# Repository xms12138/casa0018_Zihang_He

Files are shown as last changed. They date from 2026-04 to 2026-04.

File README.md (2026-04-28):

# 💡 EchoLume: An Offline Voice-Controlled Adaptive Smart Lamp on the Edge






## 📖 Overview

Smart lamps that respond to voice are everywhere, but the dominant pattern sends audio off-device for cloud inference—trading user privacy and network dependency for accuracy. **EchoLume asks whether that trade is necessary for a simple four-command desk lamp.**

EchoLume is a fully offline, privacy-preserving smart lamp running an INT8-quantised keyword-spotting model entirely on an **Arduino Nano 33 BLE Sense (Cortex-M4F, 64 MHz)**. It processes audio locally, utilizes a lightweight 1D CNN to recognize commands (`turn_on`, `turn_off`, `reading`, `sleep`), and uses a Finite State Machine (FSM) to drive an addressable LED strip.

> **Note:** This repository is forked from the UCL CASA0018 module. All of my final project code, models, and comprehensive documentation are located in the [`Assessment`](./Assessment) directory.

---

## 🛠️ Repository Navigation & Reproduction

To replicate this project or view the source files, navigate to the [`Assessment/Projects/Final_Project`](./Assessment/Projects/Final_Project) directory.

### Directory Structure

* 📄 **[`Report/`](./Assessment/Report)**: The final academic report (`report.md`) detailing problem context, datasets, and critical reflections.
* 💻 **[`arduino/`](./Assessment/Projects/Final_Project/arduino)**: The deployment firmware (`.ino`) containing the FSM and LED control logic.
* 🧠 **[`edge_impulse/`](./Assessment/Projects/Final_Project/edge_impulse)**: Exported INT8 C++ libraries from the training pipeline.
* 📊 **[`experiments/`](./Assessment/Projects/Final_Project/experiments)**: Detailed experiment logs and JSON configs.
* 🖨️ **[`3D_Printer/`](./Assessment/Projects/Final_Project/3D_Printer)**: Enclosure CAD/STL files.

### Hardware Setup

1. **Board:** Arduino Nano 33 BLE Sense
2. **Actuator:** WS2812B Addressable LED strip (Data pin wired to `D2`, powered via the 3.3V rail).
3. **Dependencies:** Install the Edge Impulse `.zip` library (found in the `edge_impulse/` folder) into your Arduino IDE.

------

## ⚙️ System Architecture

The signal path is a highly optimized five-stage pipeline designed to fit within the stringent 100 ms real-time budget and 256 KB RAM of the Cortex-M4F.

<p align="center">
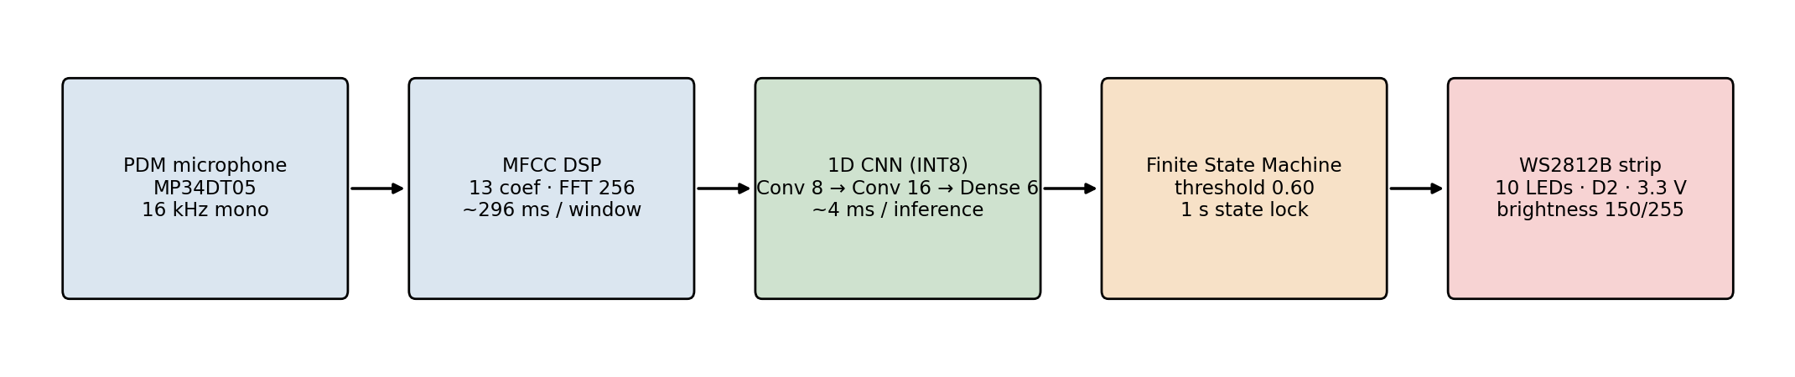
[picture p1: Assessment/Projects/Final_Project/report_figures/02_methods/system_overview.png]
System Signal Path Overview
  
</p>

1. **Audio Capture:** On-board MP34DT05 PDM microphone (16 kHz mono).
2. **DSP (MFCC):** Extracts 13 cepstral coefficients per 1 s sliding window. 
   * *Engineering Decision:* EI Autotune suggested an FFT length of 512, which cost 416 ms (unusable for real-time). **I manually reduced the FFT length to 256, dropping DSP time to 296 ms (−29%)** with no visible loss of feature separability.
3. **1D CNN (INT8):** A sub-50 KB convolutional network processes the features.
4. **Finite State Machine:** A 1-second state-lock acts as a low-pass filter, preventing erratic flickering. Predictions below a 0.60 confidence threshold are safely ignored.

<p align="center">
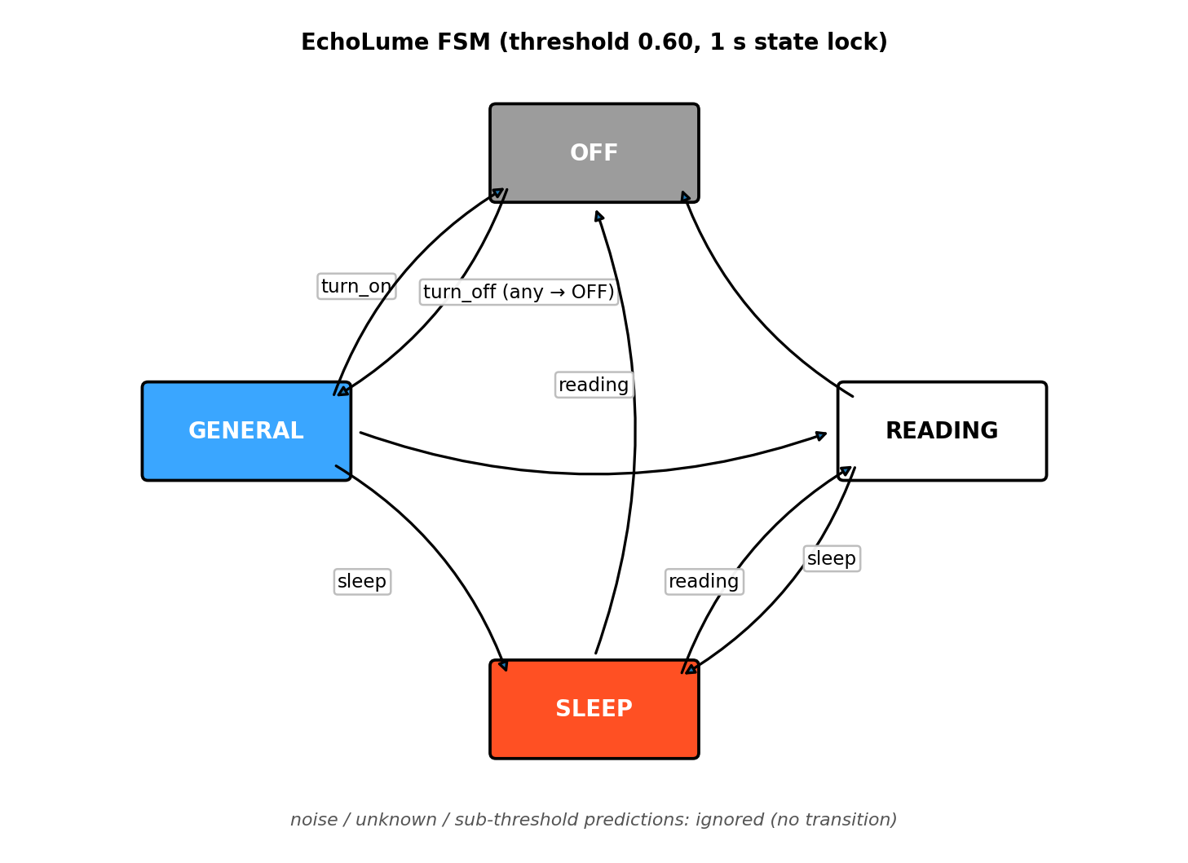
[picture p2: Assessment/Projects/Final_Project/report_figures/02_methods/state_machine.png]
FSM Diagram
  
</p>

---

## 🔬 Experiments & Model Selection

The goal was not merely to chase headline accuracy, but to find a model that fails *safely*. Three architectures were rigorously tested.

| Metric | baseline (Conv 8/16) | exp_wider (Conv 16/32) | exp_dense (No Conv) |
| --- | --- | --- | --- |
| **Test Acc (INT8 @ 0.6)** | **81.95%** | 82.93% | 61.95% ❌ |
| **`turn_on` -> `turn_off` Error** | **10.0%** | 33.3% ❌ | 23.3% ❌ |
| **Peak RAM (KB)** | 12.5 | 14.0 | 1.8 |
| **Flash (KB)** | 46.4 | 49.4 | 34.1 |
| **Inference Time (ms)** | 4 | 7 | 1 |
| **Verdict** | **Deployed (Safest Failure Mode)** | Rejected (Wrong-action failure) | Rejected (Noise blind) |

### 🔍 Key Findings
* **Capacity is not the bottleneck (Wider != Better):** Doubling the convolutional channels (`exp_wider`) increased overall accuracy by +1 pp, but caused a **3.3x rise in confidently-wrong triggers** (confusing `turn_on` for `turn_off`). The baseline model politely fails into "uncertainty" (no action), making it strictly better for an FSM application.
* **Convolutions are load-bearing:** Replacing the CNN with a Dense head (`exp_dense`) collapsed accuracy by 20 pp and made the model essentially blind to background noise (40% accuracy on `noise`). 

<p align="center">
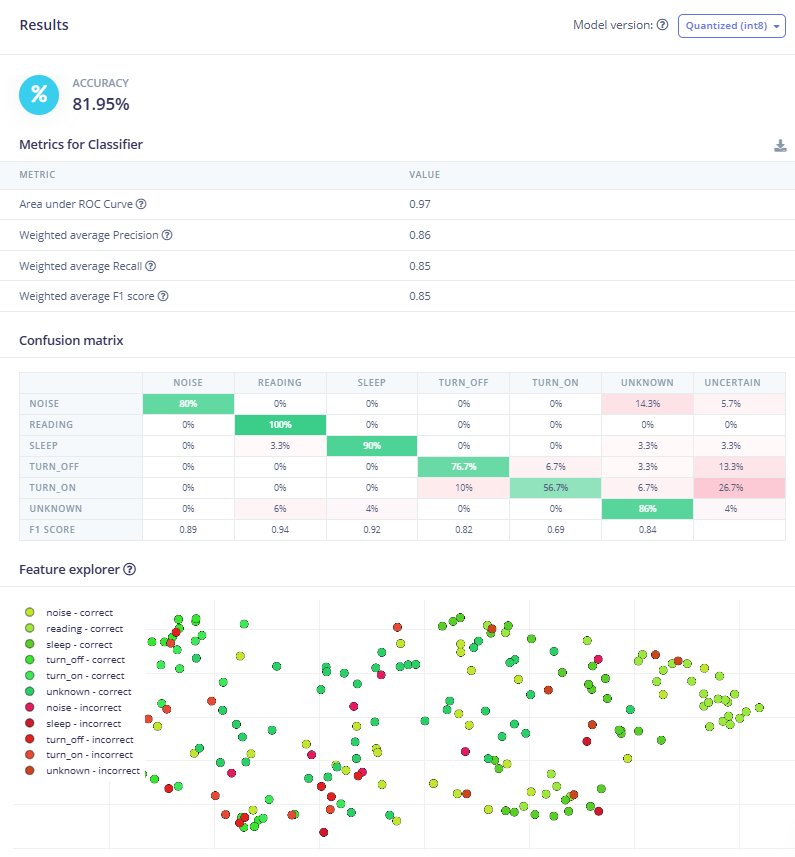
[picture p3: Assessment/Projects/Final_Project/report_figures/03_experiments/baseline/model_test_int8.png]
Baseline Confusion Matrix
  
  <br>
  <em>Figure: Baseline INT8 Test-Set Confusion Matrix. Note the safe concentration of errors in the UNCERTAIN column.</em>
</p>

---

## 📊 Real-World Performance (Live Testing)

The shipped baseline firmware was deployed on-device and tested via **100 live spoken trials** in a real-world desk environment (varying distances 0.05m–0.5m, with occasional background music).

* **Aggregate Correct Transitions:** **88.0%**
* Live recall actually *exceeded* the static Edge Impulse test set because the FSM's 1-second state lock successfully collapses uncertain acoustic frames into benign "no actions".

<p align="center">
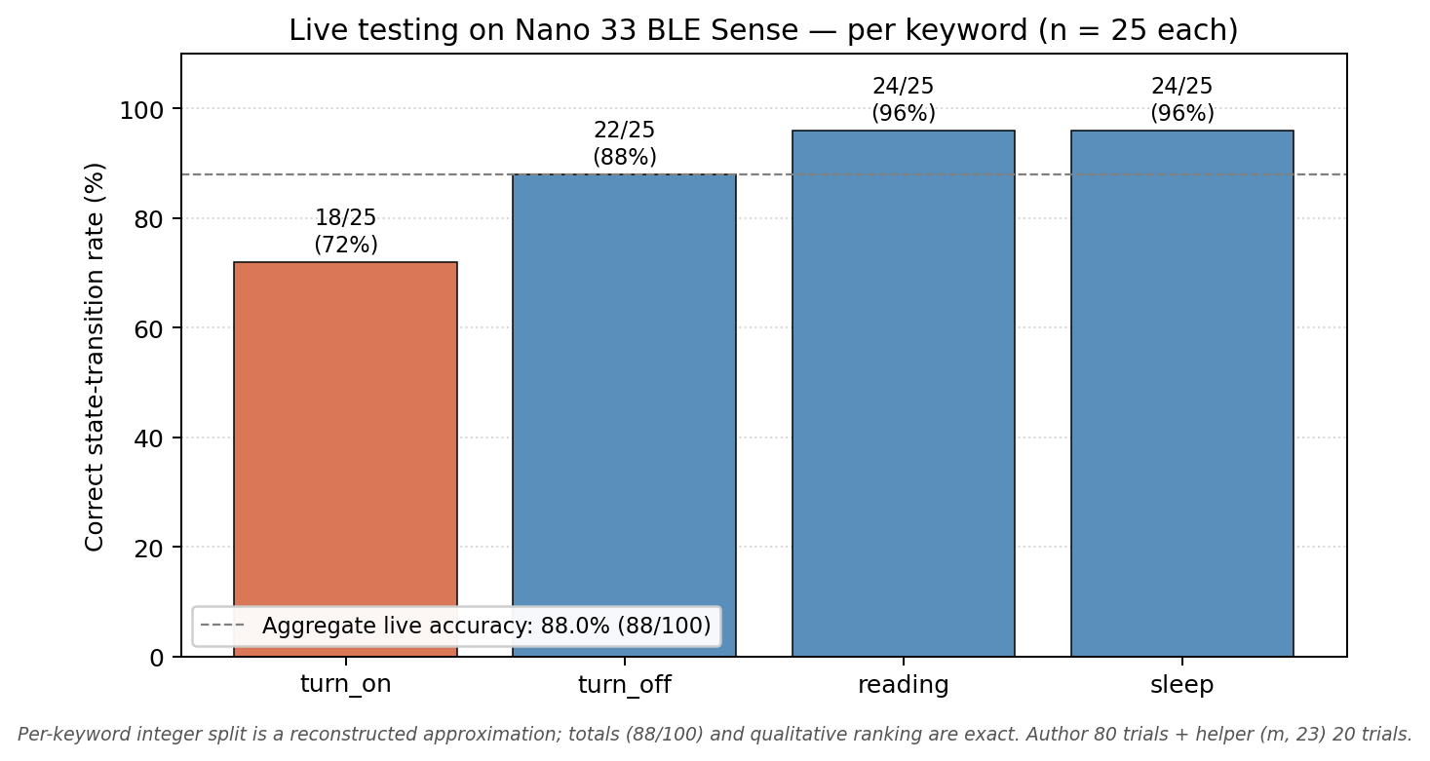
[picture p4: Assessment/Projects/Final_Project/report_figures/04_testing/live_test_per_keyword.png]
Live Testing per Keyword
  
</p>
---
*Authored by **Zihang He** for CASA0018: Deep Learning for Sensor Networks.*

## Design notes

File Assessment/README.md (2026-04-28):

# CASA0018 DL4SN Assessment Submission

**Author:** Zihang He  
**Module:** CASA0018 Deep Learning for Sensor Networks (DL4SN)

Welcome to my final assessment repository. This folder contains all the documentation, source code, and assets for my coursework, demonstrating the process of taking machine learning out of the cloud and deploying it locally on an edge device.

The centerpiece of this submission is my final project: **EchoLume**.

> **Note:** For more specific details about the project, please visit the [Main Repository](https://github.com/xms12138/casa0018_Zihang_He/tree/main).

---

## 📂 Repository Structure

In accordance with the module guidelines, this assessment repository is organized into two main parts:

### 1. [Report](./Report)
This folder contains the comprehensive documentation of my final project.
* `report.md`: The final project report (approx. 1600 words) detailing the problem context, custom data collection, iterative model testing, and critical reflection.

### 2. [Projects/Final_Project](./Projects/Final_Project)
This folder acts as the technical hub for the EchoLume project. It contains all the code and assets required to replicate the physical build and the machine learning pipeline:
* **`arduino/`**: The deployment firmware in C++ for the Arduino Nano 33 BLE Sense, integrating the Edge Impulse model, the PDM microphone, and the finite state machine (FSM) for the WS2812B LEDs.
* **`edge_impulse/`**: Exported models and configuration files from the Edge Impulse platform.
* **`experiments/`**: Documentation and data analyzing the different model architectures tested (e.g., Conv 8/16 vs. Conv 16/32 vs. Dense).
* **`3D_Printer/`**: CAD files and assets used for the physical enclosure of the smart lamp.
* **`scripts/`**: Python utility scripts used during the data processing and analysis phases.
* **`report_figures/`**: All visual assets, graphs, and hardware photos used in the main report.

---

## 💡 About the Final Project: EchoLume

**EchoLume** is an offline, privacy-preserving smart lamp running an INT8-quantised keyword-spotting model entirely on an Arduino Nano 33 BLE Sense (Cortex-M4F). 

It proves that everyday smart home interactions do not strictly require cloud connectivity. The system captures speech via the on-board PDM microphone, processes it through an MFCC front-end and a lightweight 1D CNN, and drives an addressable LED strip via a finite state machine. It responds reliably to four distinct commands (`turn_on`, `turn_off`, `reading`, `sleep`) while gracefully ignoring background noise and unknown utterances.

---

## 🚀 How to Use / Getting Started

To build and run EchoLume locally, follow these hardware and software setup instructions.

### 🛠️ Hardware Requirements
* 1x **Arduino Nano 33 BLE Sense**
* 1x **WS2812B Addressable LED Strip** (10 LEDs are used in the default configuration)
* Jumper wires and a breadboard
* (Optional) 3D printed enclosure (files available in the `3D_Printer/` folder)

### 🔌 Wiring
Connect the WS2812B LED strip to the Arduino Nano 33 BLE Sense as follows:
* **LED VCC** -> Arduino **3.3V** (Make sure brightness is capped in code to avoid drawing too much current)
* **LED GND** -> Arduino **GND**
* **LED Data (DIN)** -> Arduino **D2**

### 💻 Software Setup & Installation
1. **Install Arduino IDE:** Download and install the [Arduino IDE](https://www.arduino.cc/en/software).
2. **Install Board Core:** Open the Arduino IDE, go to `Tools -> Board -> Boards Manager...`, and install the **Arduino Mbed OS Nano Boards** package.
3. **Install the Edge Impulse Library:**
   * Locate the custom Edge Impulse exported `.zip` library in this repository under `Projects/Final_Project/edge_impulse/`.
   * In the Arduino IDE, navigate to `Sketch -> Include Library -> Add .ZIP Library...` and select the `.zip` file.
4. **Flash the Firmware:**
   * Open the EchoLume firmware sketch located at `Projects/Final_Project/arduino/echolume/echolume.ino`.
   * Connect your Arduino Nano 33 BLE Sense to your computer. Select the correct Board and Port in the `Tools` menu.
   * Click **Upload**.

### 🎙️ Usage
Once the firmware is uploaded and the board is powered on:
1. The on-board PDM microphone will continuously listen to the environment.
2. Speak one of the four action keywords: **"Turn on"**, **"Turn off"**, **"Reading"**, or **"Sleep"**.
3. The LED strip will adapt to the corresponding lighting scene.
   * *Note: The Finite State Machine (FSM) incorporates a 1-second state lock to prevent erratic flickering, and it ignores audio classifications that fall below the 0.60 confidence threshold.*

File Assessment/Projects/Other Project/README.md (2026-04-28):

### [CASA0018 Lab 4: 部署余弦波模型到 Arduino](Assessment/Projects/Other%20Project/Lab4%20cos/)

- **训练笔记本**: [查看 sin to cos.ipynb](Assessment/Projects/Other%20Project/Lab4%20cos/sin%20to%20cos.ipynb)
- **Arduino 源代码**: [查看 hello_casa_custom 文件夹](Assessment/Projects/Other%20Project/Lab4%20cos/hello_casa_custom/)
- **模型文件**: [查看导出的 model.cpp 和 model.h](Assessment/Projects/Other%20Project/Lab4%20cos/models/)

#### 运行效果演示：
Arduino 2秒循环呼吸灯演示

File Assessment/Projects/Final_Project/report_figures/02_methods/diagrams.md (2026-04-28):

# Self-drawn diagrams (mermaid sources)

These three diagrams render natively on GitHub and can be embedded into the
report by either pasting the mermaid source, or by exporting each block to PNG
via the Mermaid Live Editor (https://mermaid.live) into this same directory.

---

## 1. System overview

```mermaid
flowchart LR
    A[Onboard PDM mic<br/>MP34DT05<br/>16 kHz mono] --> B[MFCC DSP<br/>13 coef · FFT 256<br/>~296 ms / window]
    B --> C[1D CNN INT8<br/>Conv 8 → Conv 16 → Dense 6<br/>~4 ms / inference]
    C --> D{best_value<br/>≥ 0.60 ?}
    D -- no --> A
    D -- yes --> E[Finite State Machine<br/>OFF · GENERAL · READING · SLEEP<br/>1 s state lock]
    E --> F[WS2812B strip<br/>10 LEDs · D2 · 3.3 V<br/>brightness 150/255]
```

---

## 2. State machine

```mermaid
stateDiagram-v2
    direction LR
    [*] --> OFF
    OFF --> GENERAL: turn_on
    GENERAL --> READING: reading
    GENERAL --> SLEEP: sleep
    READING --> SLEEP: sleep
    SLEEP --> READING: reading
    GENERAL --> OFF: turn_off
    READING --> OFF: turn_off
    SLEEP --> OFF: turn_off

    note right of OFF
        Colour: all off
    end note
    note right of GENERAL
        Colour: ice blue (0,255,200)
    end note
    note right of READING
        Colour: pure white (255,255,255)
    end note
    note right of SLEEP
        Colour: warm orange-red (255,50,0)
    end note
```

`noise` and `unknown` predictions are silently ignored (no transition).
Predictions with `best_value < 0.60` are treated as `uncertain` and ignored.
A 1 s state lock after each accepted transition prevents a single utterance
being re-classified across multiple frames.

---

## 3. Model architecture (baseline)

```mermaid
flowchart TB
    A["Input<br/>637 features<br/>flat vector from MFCC"] --> B["Reshape<br/>13 columns<br/>(time × cepstral)"]
    B --> C["Conv1D<br/>8 filters · kernel 3 · ReLU"]
    C --> D["Dropout 0.25"]
    D --> E["Conv1D<br/>16 filters · kernel 3 · ReLU"]
    E --> F["Dropout 0.25"]
    F --> G["Flatten"]
    G --> H["Dense 6 · softmax<br/>{turn_on, turn_off, reading, sleep, noise, unknown}"]
```

INT8 quantization applied post-training. On-device estimate (Cortex-M4F):
~4 ms inference, ~12.5 KB peak RAM, ~46.4 KB flash.

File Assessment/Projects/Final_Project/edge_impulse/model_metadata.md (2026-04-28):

# Model Metadata

- **Edge Impulse project URL (public)**: https://studio.edgeimpulse.com/public/973891/latest
- **Project ID**: 973891
- **Project name (EI Studio)**: `xms.12138-project-1`
- **Exported library**: `exported_library/ei-xms.12138-project-1-arduino-1.0.1-impulse-#1.zip`
- **Last sync**: 2026-04-28

## Impulse summary

| Block | Setting | Value |
|---|---|---|
| DSP | type | MFCC |
| DSP | coefficients | 13 |
| DSP | frame length / stride | 0.025 s / 0.02 s |
| DSP | FFT length | 256 (manual; autotune default 512 — see exp_log) |
| DSP | filter number | 32 |
| DSP | low frequency | 80 Hz |
| DSP | output features | 637 (reshape 13 cols) |
| Model | architecture | EI default 1D CNN (Conv 8 → Conv 16 → Flatten → Dense 6) |
| Model | dropout | 0.25 (×2) |
| Training | epochs / lr / batch | 200 / 0.005 / 32 |
| Training | augmentation | Add noise Low + Mask time Low + Mask freq Low + Warp time on |
| Training | learned optimizer | disabled |
| Quantization | mode | INT8 (also Float32 evaluated for comparison) |

## Performance snapshot — baseline (INT8 unless noted)

| Metric | Value |
|---|---|
| Validation accuracy (INT8) | 94.5% |
| Validation accuracy (Float32) | 95.1% |
| Test accuracy @ threshold 0.6 (INT8) | 81.95% |
| Test accuracy @ threshold 0.6 (Float32) | 82.44% |
| Quantization Δ (test) | −0.49 pp |
| Validation → Test gap | −12.55 pp |
| Worst-class F1 (INT8 test) | turn_on 0.69 |
| On-device inference (INT8 est.) | ~4 ms |
| On-device DSP | 296 ms |
| Peak RAM (INT8 est.) | ~12.5 KB |
| Flash (INT8 est.) | ~46.4 KB |

## Live testing (deployed Nano 33 BLE Sense, threshold 0.6)

| Metric | Value |
|---|---|
| Total trials | 100 |
| Correct state transitions | 88 |
| Aggregate live accuracy | 88.0% |

See `experiments/exp_log.md` entry 2026-04-28 for protocol, per-speaker split, and per-keyword breakdown.

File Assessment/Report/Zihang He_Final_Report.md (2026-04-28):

# EchoLume: An Offline Voice-Controlled Adaptive Smart Lamp on the Edge

**Zihang He** &nbsp;·&nbsp; [GitHub](https://github.com/xms12138/casa0018_Zihang_He/tree/main/Assessment) &nbsp;·&nbsp; [Edge Impulse public project](https://studio.edgeimpulse.com/public/973891/latest)

## Introduction

Smart lamps that respond to voice are now everywhere, but the dominant pattern — Alexa, Google Home and similar — sends audio off-device for cloud inference, trading user privacy and a working internet connection for accuracy. EchoLume asks whether that trade is necessary for a four-command desk lamp.

EchoLume is an offline, privacy-preserving smart lamp running an INT8-quantised keyword-spotting model entirely on an Arduino Nano 33 BLE Sense (Cortex-M4F, 64 MHz). Audio never leaves the board: the on-board PDM microphone captures speech, an MFCC front-end and a 1D CNN classify it, and a finite state machine drives a WS2812B addressable LED strip. Four control words — `turn_on`, `turn_off`, `reading`, `sleep` — switch the lamp between ambient, reading and rest scenes; two distractor classes (`noise`, `unknown`) absorb non-target sounds.

The implementation builds on Warden's _Speech Commands_ dataset (Warden, 2018) and the _Hello Edge_ line of micro-controller keyword spotting (Zhang et al., 2017), with Edge Impulse as the training-and-export harness. The contribution this report documents is not a novel architecture but a structured exploration of the design space — what stays in budget, what improves the failure mode, and what does not.

<p align="center">
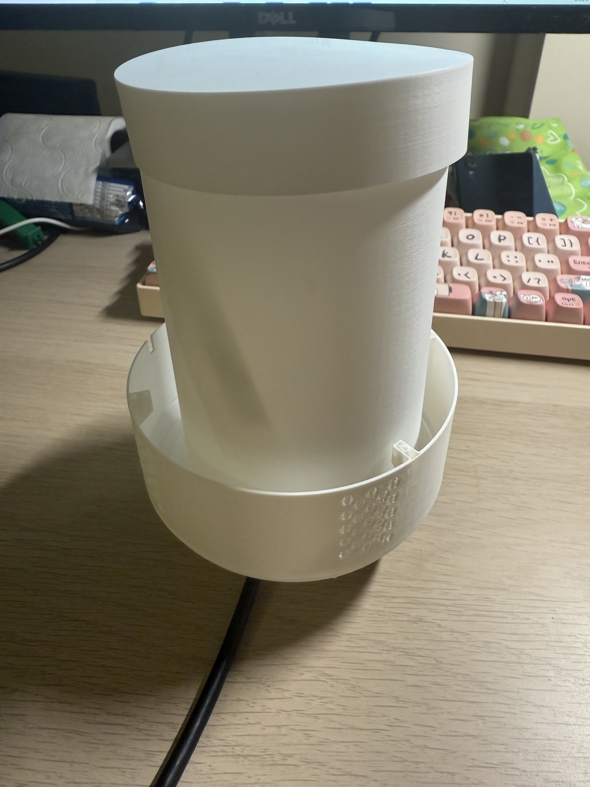
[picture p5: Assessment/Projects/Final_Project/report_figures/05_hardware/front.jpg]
  
</p>

_Figure 1. EchoLume on a desk._

## Research Question

Can a sub-50 KB INT8 keyword-spotting model deployed on a Cortex-M4F microcontroller deliver reliable, fully offline voice control of an addressable RGB lamp under realistic desk-use conditions?

## Application Overview

The signal path is a five-stage pipeline (Figure 2). The on-board MP34DT05 PDM microphone samples at 16 kHz mono. An MFCC block produces a 637-feature vector per 1 s sliding window — 13 cepstral coefficients across roughly 49 frames — which is reshaped to a 13-column matrix and fed to a 1D CNN exported as INT8 from Edge Impulse. The classifier outputs a softmax over six classes; predictions whose top-1 probability falls below 0.60 are treated as `uncertain` and ignored.

Above the classifier sits a finite state machine (Figure 3) that converts the keyword stream into a lamp scene. Four lamp states (OFF, GENERAL, READING, SLEEP) are linked by legal transitions: `turn_on` is honoured only from OFF, `turn_off` from any non-OFF state, and `reading` and `sleep` toggle scenes within the on-states. A 1 s state-lock prevents a single utterance being re-classified across consecutive frames. The LED strip (10 WS2812B pixels driven from the Nano's 3.3 V rail on D2) renders the active state as ice-blue, white or warm orange-red.

This separation matters: the FSM lets the system fail gracefully. If the classifier returns a low-confidence prediction, the FSM drops it; if it returns an illegal one (e.g. `sleep` while OFF), the FSM ignores it. Failures collapse into "no action" rather than "wrong action".

<p align="center">
  
</p>

_Figure 2. EchoLume signal-path overview._

<p align="center">
  
</p>

_Figure 3. Lamp state machine (threshold 0.60, 1 s state lock). `noise`, `unknown` and sub-threshold predictions are ignored._

## Data

The dataset comprises 1,025 one-second utterances across six classes (Figure 4). The four action classes (`turn_on`, `turn_off`, `reading`, `sleep`) are 150 self-recorded samples each, captured on the same Nano 33 BLE Sense microphone the system later runs inference on, removing one source of acoustic distribution shift between training and deployment.

Two distractor classes back the action vocabulary against a noisy environment. `noise` (175 samples) is drawn from the MS-SNSD noisy-speech dataset (Reddy et al., 2019) via Edge Impulse's public datasets. `unknown` (250 samples) is a balanced subset of Google Speech Commands V2 (Warden, 2018) with the four target words filtered out. The 80/20 train/test split is applied uniformly; Edge Impulse subdivides 20 % of training for validation during model fitting.

The action classes are balanced and the distractor classes deliberately oversampled, on the heuristic that a keyword spotter's ability to _not_ fire matters as much as its ability to fire. The single largest known limitation is that all 600 action samples come from one primary speaker — a generalisation risk addressed in _Results_.

<p align="center">
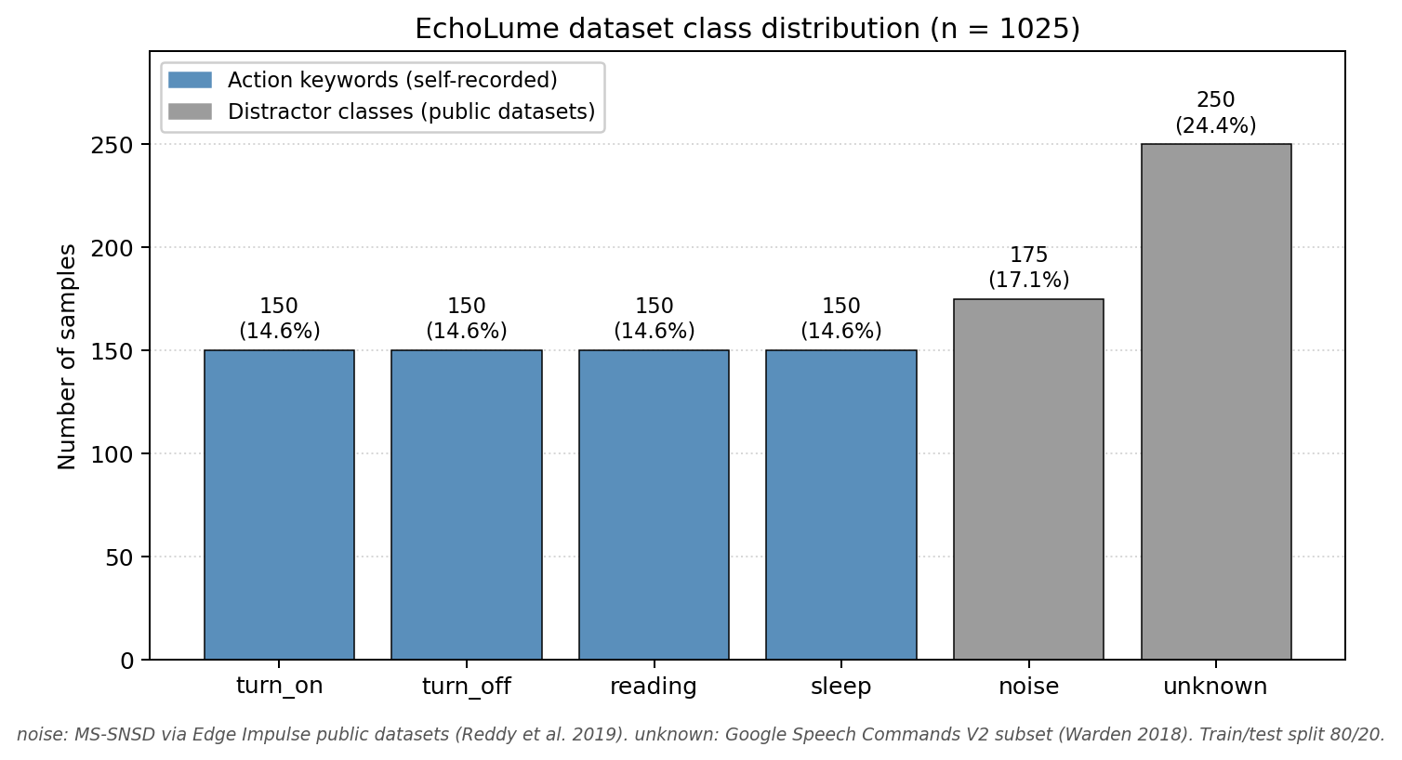
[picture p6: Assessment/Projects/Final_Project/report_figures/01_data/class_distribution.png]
  
</p>

_Figure 4. Dataset class distribution (n = 1,025)._

## Model

The baseline model is the Edge Impulse default 1D CNN (Figure 5): two stacked Conv1D blocks (8 and 16 filters, kernel 3, ReLU, each followed by 25 % dropout), a Flatten, and a six-way softmax. Reshaping the 637-feature input to 13 columns gives the convolutions the time × cepstral structure they need to learn local spectro-temporal patterns; the modest filter count keeps INT8 weights well under the Nano's 1 MB flash and 256 KB RAM.

The DSP block was the first non-trivial design decision. Edge Impulse's autotune recommended an FFT length of 512, which produced a per-window DSP cost of 416 ms on the Cortex-M4F — over four times the 100 ms real-time budget for a keyword loop. Manually reducing the FFT length to 256 cut DSP to 296 ms (−29 %) with no visible loss of separability in the feature explorer. Inference itself remains 4 ms; DSP is the dominant cost, and the choice is a deliberate trade between window-rate latency and frequency resolution.

Training used 200 epochs, learning rate 0.005, batch 32, with the Edge Impulse augmentation stack at "Low" intensity (additive noise, time and frequency masking, time warp). Quantisation is post-training INT8.

<p align="center">
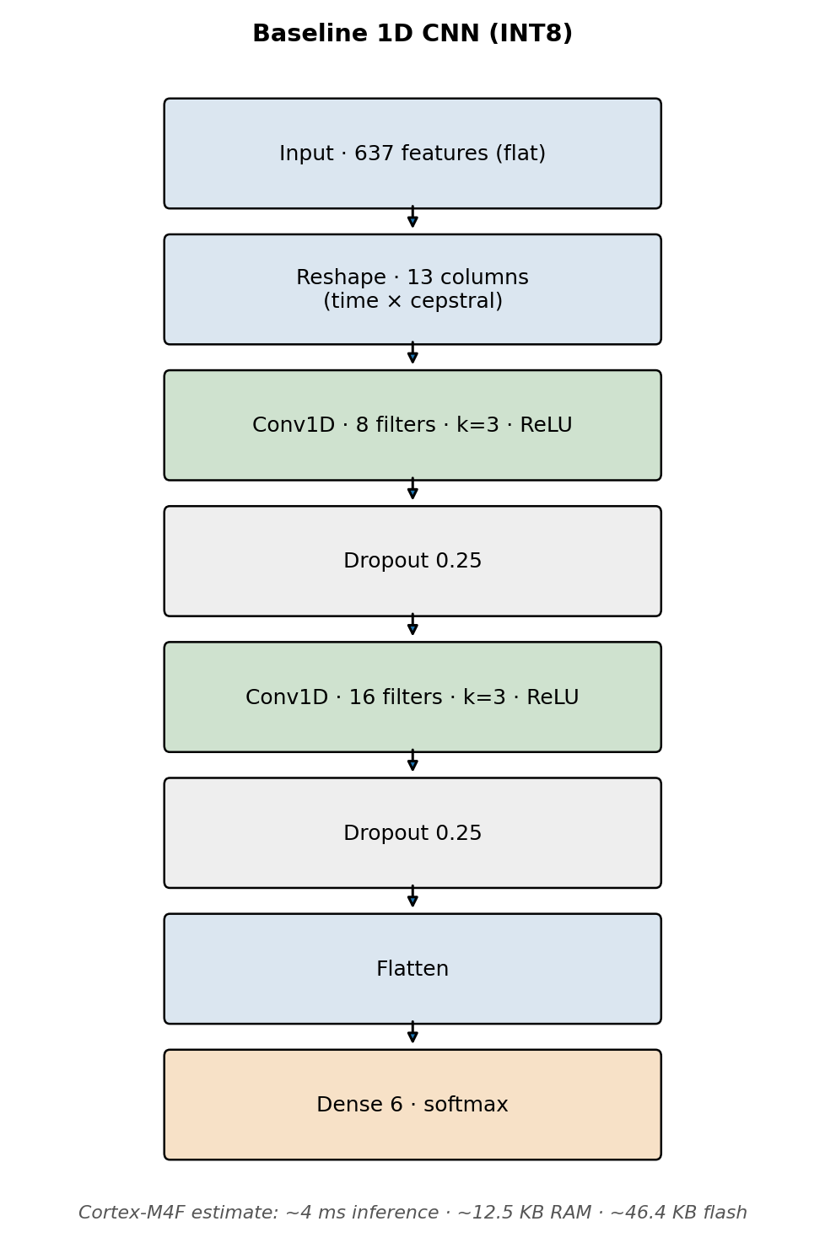
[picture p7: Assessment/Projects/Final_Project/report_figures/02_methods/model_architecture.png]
  
</p>

_Figure 5. Baseline 1D CNN architecture._

## Experiments

Three architectures were compared on the same DSP, augmentation and training schedule. The goal was not to chase headline accuracy, but to test which architectural choices are load-bearing for this data and which are decorative.

**Baseline (Conv 8/16).** Validation 94.5 % INT8 (95.1 % Float32); test 81.95 % INT8 at threshold 0.6 (82.44 % Float32). The val→test gap of −12.55 pp is far larger than the −0.49 pp INT8 quantisation cost — generalisation, not quantisation, is the bottleneck. Per-class F1 ranks `reading` 0.94, `sleep` 0.92, `noise` 0.89, `unknown` 0.84, `turn_off` 0.82, `turn_on` 0.69. The `turn_on`/`turn_off` pair is the structural weak spot: the two utterances share their first ~800 ms; only the trailing fricative differs. On-device profile: 4 ms inference, 12.5 KB RAM, 46.4 KB flash.

**exp_wider (Conv 16/32).** Doubling the convolutional channels was hypothesised to capture finer fricative-tail differences. Headline metrics improved (val 96.3 % INT8, test 82.93 %, `turn_on` F1 → 0.76), but the per-class breakdown reveals a worse failure mode: `turn_on → turn_off` confusion rose from 10 % to 33 % (×3.3). The wider model trades polite "uncertain → no response" failures for confident "wrong-action" failures — a regression for a state-machine application. Capacity is not the bottleneck; calibration is.

**exp_dense (no Conv).** Replacing both Conv1D blocks with a single Dense 32 head tested whether MFCC features alone make the convolutions redundant. They do not: test accuracy collapses to 61.95 % (−20 pp), `noise` to 40 %, `turn_on` to 43 %. The dense head memorises validation patterns (its `turn_on` validation recall is 90 %) but does not generalise. Convolutions do real work even at this scale, and the experiment locks Conv1D in as load-bearing for the rest of the design.

| Metric | baseline | exp_wider | exp_dense |
| --- | --- | --- | --- |
| Val acc (INT8) | 94.5 % | **96.3 %** | 75.0 % |
| Test acc @ 0.6 (INT8) | 81.95 %  | **82.93 %** | 61.95 % |
| `turn_on` F1 | 0.69 | 0.76 | 0.55 |
| `turn_on → turn_off`  | 10 % | **33 %** | 23 % |
| Inference (ms) | 4 | 7 | 1 |
| Peak RAM (KB) | 12.5 | 14.0 | 1.8 |
| Flash (KB) | 46.4 | 49.4 | 34.1 |
| Verdict | shipped  | unsafe failure mode | confirms Conv is load-bearing |

_Table 1. Cross-experiment summary (INT8 unless noted)._

<p align="center">
  
</p>

_Figure 6. Baseline INT8 test-set confusion matrix (threshold 0.6)._

## Results and Observations

The shipped firmware uses the baseline INT8 model. A live-testing session of 100 trials (4 keywords × 25 trials, threshold 0.6, 1 s state lock) was conducted as a real-world check. Eighty trials were performed by the author and twenty by an additional speaker (m, 23, no prior exposure); mouth-to-mic distance varied 0.05–0.5 m, with half the trials run with light background music playing. A trial counted as correct only if the LED strip transitioned to the intended state.

The aggregate result was **88/100 = 88.0 %** correct transitions — author 71/80, helper 17/20. The per-keyword breakdown shown in Figure 7 (24/25 `reading`, 24/25 `sleep`, 22/25 `turn_off`, 18/25 `turn_on`) is approximate: per-trial outcomes were not logged at the time, so the integer split across keywords is reconstructed from in-session observations and is consistent with the baseline EI test-set ranking. Aggregates and qualitative ranking are exact.

Two findings stood out. First, live recall exceeded EI test-set recall on every keyword (Figure 8). The likely explanations are speaker overlap with training data, and the more lenient FSM-level criterion: the state-lock collapses many uncertain frames into a benign no-action rather than an explicit miss. Second, the dominant failure mode was no-response on `turn_on`, never wrong-state on `turn_on` — exactly the pattern predicted by the baseline confusion matrix. A separate failure mode appeared during the helper session: 1–2 false triggers caused by a bystander speaking nearby. These were not counted in the 12 listed failures because they were not logged at the time, but they are worth flagging as a real-world weakness.

<p align="center">
  
</p>

_Figure 7. Live-testing results per keyword (n = 25 each)._

<p align="center">
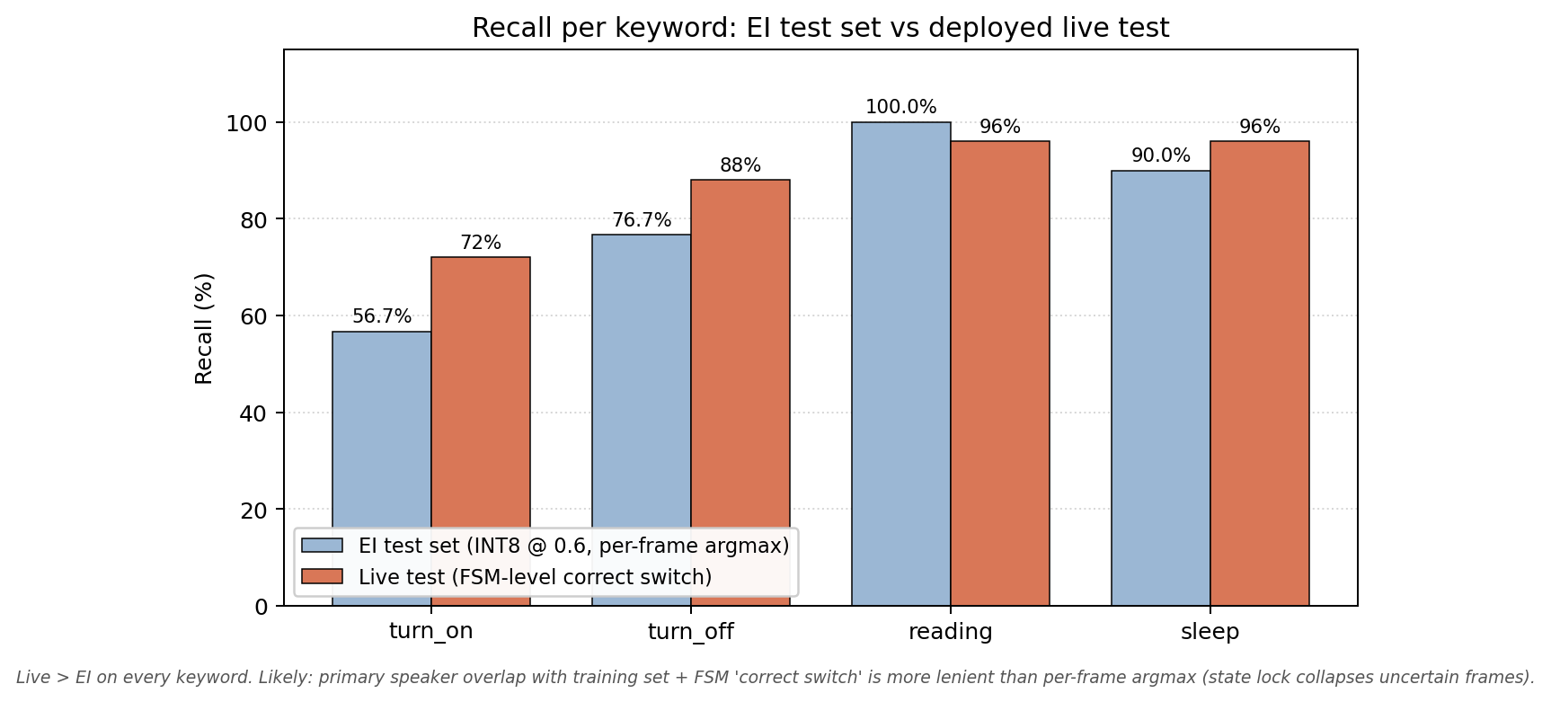
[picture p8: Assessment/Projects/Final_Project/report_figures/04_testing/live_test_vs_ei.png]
  
</p>

_Figure 8. Live test versus Edge Impulse test-set recall, per keyword._

**Limitations.** Three structural weaknesses are visible in the data above. (1) `turn_on` and `turn_off` share their leading 800 ms, leaving the model dependent on the trailing fricative — the worst class in every experiment. (2) The −12.55 pp val→test gap reflects a real distribution shift, almost certainly tied to (3) the dataset being recorded by a single primary speaker. Two further issues warrant brief mention: the 296 ms DSP cost still exceeds the 100 ms real-time budget but does not break functionality, since inference itself is only 4 ms; and the confidence threshold trades coverage for safety — 0.5 raises recall but lifts wrong-state errors, while 0.6 is the conservative pick. The bystander false-trigger mode points to a missing capability: without a wake-word gate or voice-activity threshold, sub-threshold utterances from the environment can still nudge state.

**What would I do next.** A multi-speaker re-recording of the action classes would directly attack the val→test gap. A wake-word stage (e.g. "EchoLume, …") would suppress bystander triggers. A small depthwise-separable variant of the Conv1D backbone is a candidate that keeps the Cortex-M4F budget within reach while improving calibration on the `turn_on`/`turn_off` boundary.

## Bibliography

1. Reddy, C. K. A., Beyrami, E., Pool, J., Cutler, R., Srinivasan, S., & Gehrke, J. (2019). _A Scalable Noisy Speech Dataset and Online Subjective Test Framework._ Interspeech 2019. https://arxiv.org/abs/1909.08050
2. Warden, P. (2018). _Speech Commands: A Dataset for Limited-Vocabulary Speech Recognition._ arXiv:1804.03209. https://arxiv.org/abs/1804.03209
3. Zhang, Y., Suda, N., Lai, L., & Chandra, V. (2017). _Hello Edge: Keyword Spotting on Microcontrollers._ arXiv:1711.07128. https://arxiv.org/abs/1711.07128

---

## Declaration of Authorship

I, Zihang He, confirm that the work presented in this assessment is my own. Where information has been derived from other sources, I confirm that this has been indicated in the work.

_Zihang He_

2026-04-28

Word count: 1648 (body text only — title, captions, tables, bibliography and declaration excluded).

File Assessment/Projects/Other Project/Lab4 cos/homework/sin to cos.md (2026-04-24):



# Train a Simple TensorFlow Lite for Microcontrollers model

This notebook demonstrates the process of training a 2.5 kB model using TensorFlow and converting it for use with TensorFlow Lite for Microcontrollers.

Deep learning networks learn to model patterns in underlying data. Here, we're going to train a network to model data generated by a [sine](https://en.wikipedia.org/wiki/Sine) function. This will result in a model that can take a value, `x`, and predict its sine, `y`.

The model created in this notebook is used in the [hello_world](https://github.com/tensorflow/tensorflow/tree/master/tensorflow/lite/micro/examples/hello_world) example for [TensorFlow Lite for MicroControllers](https://www.tensorflow.org/lite/microcontrollers/overview).

<table class="tfo-notebook-buttons" align="left">
  <td>
    <a target="_blank" href="https://colab.research.google.com/github/tensorflow/tensorflow/blob/master/tensorflow/lite/micro/examples/hello_world/train/train_hello_world_model.ipynb">Run in Google Colab</a>
  </td>
  <td>
    <a target="_blank" href="https://github.com/tensorflow/tensorflow/blob/master/tensorflow/lite/micro/examples/hello_world/train/train_hello_world_model.ipynb">View source on GitHub</a>
  </td>
</table>

## Configure Defaults
Define some variables to point to file locations.

```python
# Define paths to model files
import os
MODELS_DIR = 'models/'
if not os.path.exists(MODELS_DIR):
    os.mkdir(MODELS_DIR)
MODEL_TF = MODELS_DIR + 'model.keras'
MODEL_NO_QUANT_TFLITE = MODELS_DIR + 'model_no_quant.tflite'
MODEL_TFLITE = MODELS_DIR + 'model.tflite'
MODEL_TFLITE_MICRO = MODELS_DIR + 'model.cc'
```

## Setup Environment

Import Dependencies and give them some aliases so that they are easier to read in the code.

We set a random number seed so that you can get repeatable model results or you can tweak it to vary the model output if you want to experiment. Note - if you set a different seed number your graphs and results will look different!

```python
# TensorFlow is an open source machine learning library
import tensorflow as tf

# Keras is TensorFlow's high-level API for deep learning
from tensorflow import keras
# Numpy is a math library
import numpy as np
# Pandas is a data manipulation library
import pandas as pd
# Matplotlib is a graphing library
import matplotlib.pyplot as plt
# Math is Python's math library
import math

# Set seed for experiment reproducibility
seed = 1337
np.random.seed(seed)
tf.random.set_seed(seed)
```

## Creating a Dataset

### 1. Generate Data

The code in the following cell will generate a set of random `x` values, calculate their sine values, and display them on a graph.

Note that we shuffle the values so that they are not in order which makes the splitting of training, validation and test data easier at the next stage.

```python
# Number of sample datapoints
SAMPLES = 1000

# Generate a uniformly distributed set of random numbers in the range from
# 0 to 2π, which covers a complete sine wave oscillation
x_values = np.random.uniform(
    low=0, high=2*math.pi, size=SAMPLES).astype(np.float32)

# Shuffle the values to guarantee they're not in order
np.random.shuffle(x_values)

# Calculate the corresponding sine values
y_values = np.cos(x_values).astype(np.float32)

# Plot our data. The 'b.' argument tells the library to print blue dots.
plt.plot(x_values, y_values, 'b.')
plt.show()
```

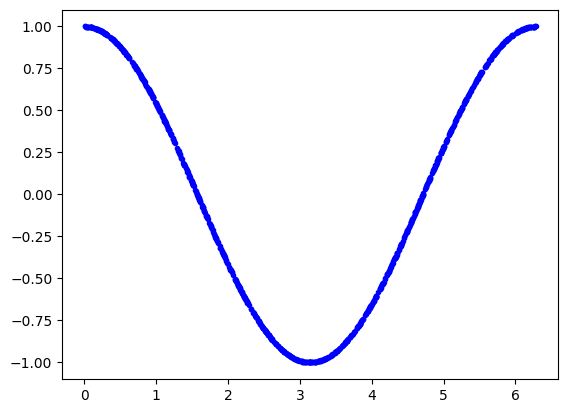
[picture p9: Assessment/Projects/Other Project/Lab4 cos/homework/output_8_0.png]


### 2. Add Noise
Since it was generated directly by the sine function, our data fits a nice, smooth curve.

However, machine learning models are good at extracting underlying meaning from messy, real world data. To demonstrate this, we can add some noise to our data to approximate something more life-like.

In the following cell, we'll add some random noise to each value, then draw a new graph:

```python
# Add a small random number to each y value
y_values += 0.1 * np.random.randn(*y_values.shape)

# Plot our data
plt.plot(x_values, y_values, 'b.')
plt.show()
```

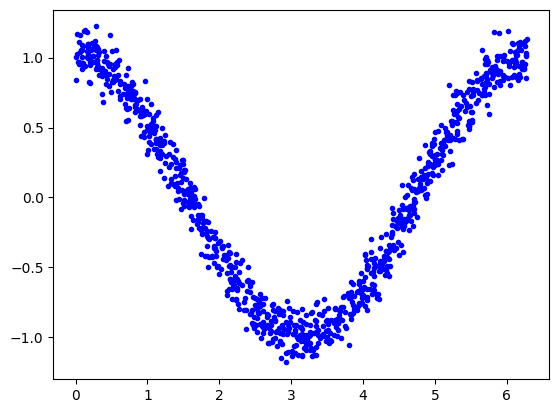
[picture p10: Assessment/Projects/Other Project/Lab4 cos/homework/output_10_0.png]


### 3. Split the Data
We now have a noisy dataset that approximates real world data. We'll be using this to train our model.

To evaluate the accuracy of the model we train, we'll need to compare its predictions to real data and check how well they match up. This evaluation happens during training (where it is referred to as validation) and after training (referred to as testing).

The data is split as follows:
  1. Training: 60%
  2. Validation: 20%
  3. Testing: 20%

The following code will split our data and then plots each set as a different color:

```python
# We'll use 60% of our data for training and 20% for testing. The remaining 20%
# will be used for validation. Calculate the indices of each section.
TRAIN_SPLIT =  int(0.6 * SAMPLES)
TEST_SPLIT = int(0.2 * SAMPLES + TRAIN_SPLIT)

# Use np.split to chop our data into three parts.
# The second argument to np.split is an array of indices where the data will be
# split. We provide two indices, so the data will be divided into three chunks.
x_train, x_test, x_validate = np.split(x_values, [TRAIN_SPLIT, TEST_SPLIT])
y_train, y_test, y_validate = np.split(y_values, [TRAIN_SPLIT, TEST_SPLIT])

# Double check that our splits add up correctly
assert (x_train.size + x_validate.size + x_test.size) ==  SAMPLES

# Plot the data in each partition in different colors:
plt.plot(x_train, y_train, 'b.', label="Train")
plt.plot(x_test, y_test, 'r.', label="Test")
plt.plot(x_validate, y_validate, 'y.', label="Validate")
plt.legend()
plt.show()
```

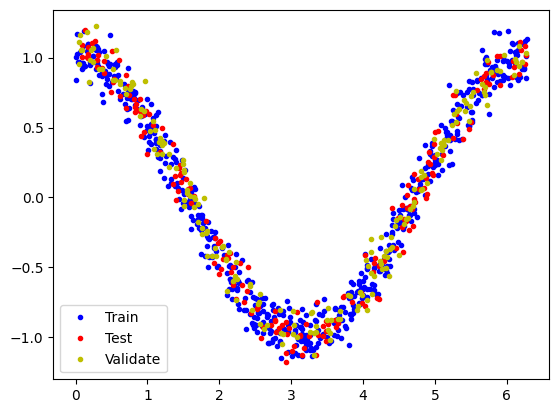
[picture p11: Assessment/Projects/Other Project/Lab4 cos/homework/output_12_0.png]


## Training

### 1. Design the Model
We're going to build a simple neural network model that will take an input value (in this case, `x`) and use it to predict a numeric output value (the sine of `x`). This type of problem is called a _regression_. It will use _layers_ of _neurons_ to attempt to learn any patterns underlying the training data, so it can make predictions.

To begin with, we'll define two layers. The first layer takes a single input (our `x` value) and runs it through 8 neurons. Based on this input, each neuron will become _activated_ to a certain degree based on its internal state (its _weight_ and _bias_ values). A neuron's degree of activation is expressed as a number. Remember:
**activation = activation_function((input * weight) + bias)** - but we don't see this here since it is handled under the hood by Keras.

The activation numbers from our first layer will be fed as inputs to our second layer, which is a single neuron. It will apply its own weights and bias to these inputs and calculate its own activation, which will be output as our `y` value.

The code in the following cell defines our model using [Keras](https://www.tensorflow.org/guide/keras), TensorFlow's high-level API for creating deep learning networks.

```python
# We'll use Keras to create a simple model architecture
model_1 = tf.keras.Sequential()

# First layer takes a scalar input and feeds it through 8 "neurons". The
# neurons decide whether to activate based on the 'relu' activation function.
model_1.add(keras.layers.Dense(32, activation='relu', input_shape=(1,)))

# Final layer is a single neuron, since we want to output a single value
model_1.add(keras.layers.Dense(1))
```

Once the network is defined, we _compile_ it, specifying parameters that determine how it will be trained:

```python
# Compile the model using the standard 'adam' optimizer and
# the mean squared error or 'mse' loss function for regression and mean abs error as a metric.
model_1.compile(optimizer='rmsprop', loss='mse', metrics=['mae'])
model_1.summary()
```

    Model: "sequential"
    _________________________________________________________________
     Layer (type)                Output Shape              Param #   
    =================================================================
     dense (Dense)               (None, 32)                64        
                                                                     
     dense_1 (Dense)             (None, 1)                 33        
                                                                     
    =================================================================
    Total params: 97
    Trainable params: 97
    Non-trainable params: 0
    _________________________________________________________________

### 2. Train the Model
Once we've defined the model, we can use our data to _train_ it. Training involves passing an `x` value into the neural network, checking how far the network's output deviates from the expected `y` value, and adjusting the neurons' weights and biases so that the output is more likely to be correct the next time.

Training runs this process on the full dataset multiple times, and each full run-through is known as an epoch. The number of **_epochs_** to run during training is a parameter we can set.

During each epoch, data is run through the network in multiple batches. For each batch, several pieces of data are passed into the network, producing output values. These outputs' correctness is measured in aggregate and the network's weights and biases are adjusted accordingly, once per batch. The **_batch size_** is also a parameter we can set.

The code in the following cell **uses the `x` and `y` values from our training data to train the model. It runs for 500 _epochs_, with 64 pieces of data in each _batch_. We also pass in some data for _validation_**. As you will see when you run the cell, training can take a while to complete:

```python
# Train the model on our training data while validating on our validation set
history_1 = model_1.fit(x_train, y_train, epochs=400, batch_size=32,
                        validation_data=(x_validate, y_validate))
```

    Epoch 1/400
    19/19 [==============================] - 1s 11ms/step - loss: 0.5163 - mae: 0.6428 - val_loss: 0.4524 - val_mae: 0.5933
    Epoch 2/400
    19/19 [==============================] - 0s 6ms/step - loss: 0.5146 - mae: 0.6437 - val_loss: 0.4522 - val_mae: 0.5932
    Epoch 3/400
    19/19 [==============================] - 0s 5ms/step - loss: 0.5162 - mae: 0.6441 - val_loss: 0.4517 - val_mae: 0.5929
    Epoch 4/400
    19/19 [==============================] - 0s 5ms/step - loss: 0.5130 - mae: 0.6421 - val_loss: 0.4518 - val_mae: 0.5928
    Epoch 5/400
    19/19 [==============================] - 0s 5ms/step - loss: 0.5109 - mae: 0.6405 - val_loss: 0.4502 - val_mae: 0.5918
    Epoch 6/400
    19/19 [==============================] - 0s 5ms/step - loss: 0.5080 - mae: 0.6383 - val_loss: 0.4451 - val_mae: 0.5890
    Epoch 7/400
    19/19 [==============================] - 0s 5ms/step - loss: 0.5029 - mae: 0.6356 - val_loss: 0.4430 - val_mae: 0.5862
    Epoch 8/400
    19/19 [==============================] - 0s 6ms/step - loss: 0.4999 - mae: 0.6337 - val_loss: 0.4381 - val_mae: 0.5839
    Epoch 9/400
    19/19 [==============================] - 0s 5ms/step - loss: 0.4968 - mae: 0.6314 - val_loss: 0.4358 - val_mae: 0.5823
    Epoch 10/400
    19/19 [==============================] - 0s 5ms/step - loss: 0.4938 - mae: 0.6298 - val_loss: 0.4338 - val_mae: 0.5809
    Epoch 11/400
    19/19 [==============================] - 0s 5ms/step - loss: 0.4911 - mae: 0.6284 - val_loss: 0.4321 - val_mae: 0.5800
    Epoch 12/400
    19/19 [==============================] - 0s 5ms/step - loss: 0.4876 - mae: 0.6258 - val_loss: 0.4298 - val_mae: 0.5784
    Epoch 13/400
    19/19 [==============================] - 0s 5ms/step - loss: 0.4863 - mae: 0.6248 - val_loss: 0.4268 - val_mae: 0.5763
    Epoch 14/400
    19/19 [==============================] - 0s 5ms/step - loss: 0.4827 - mae: 0.6211 - val_loss: 0.4251 - val_mae: 0.5752
    Epoch 15/400
    19/19 [==============================] - 0s 5ms/step - loss: 0.4785 - mae: 0.6197 - val_loss: 0.4228 - val_mae: 0.5737
    Epoch 16/400
    19/19 [==============================] - 0s 5ms/step - loss: 0.4756 - mae: 0.6179 - val_loss: 0.4204 - val_mae: 0.5719
    Epoch 17/400
    19/19 [==============================] - 0s 5ms/step - loss: 0.4712 - mae: 0.6154 - val_loss: 0.4168 - val_mae: 0.5692
    Epoch 18/400
    19/19 [==============================] - 0s 5ms/step - loss: 0.4687 - mae: 0.6137 - val_loss: 0.4134 - val_mae: 0.5673
    Epoch 19/400
    19/19 [==============================] - 0s 5ms/step - loss: 0.4660 - mae: 0.6122 - val_loss: 0.4104 - val_mae: 0.5653
    Epoch 20/400
    19/19 [==============================] - 0s 5ms/step - loss: 0.4604 - mae: 0.6074 - val_loss: 0.4081 - val_mae: 0.5638
    Epoch 21/400
    19/19 [==============================] - 0s 5ms/step - loss: 0.4565 - mae: 0.6054 - val_loss: 0.4041 - val_mae: 0.5607
    Epoch 22/400
    19/19 [==============================] - 0s 5ms/step - loss: 0.4499 - mae: 0.6014 - val_loss: 0.4023 - val_mae: 0.5593
    Epoch 23/400
    19/19 [==============================] - 0s 5ms/step - loss: 0.4479 - mae: 0.5993 - val_loss: 0.3963 - val_mae: 0.5557
    Epoch 24/400
    19/19 [==============================] - 0s 5ms/step - loss: 0.4400 - mae: 0.5935 - val_loss: 0.4009 - val_mae: 0.5563
    Epoch 25/400
    19/19 [==============================] - 0s 5ms/step - loss: 0.4378 - mae: 0.5914 - val_loss: 0.3916 - val_mae: 0.5516
    Epoch 26/400
    19/19 [==============================] - 0s 6ms/step - loss: 0.4330 - mae: 0.5880 - val_loss: 0.3844 - val_mae: 0.5470
    Epoch 27/400
    19/19 [==============================] - 0s 5ms/step - loss: 0.4294 - mae: 0.5862 - val_loss: 0.3807 - val_mae: 0.5448
    Epoch 28/400
    19/19 [==============================] - 0s 5ms/step - loss: 0.4231 - mae: 0.5827 - val_loss: 0.3779 - val_mae: 0.5428
    Epoch 29/400
    19/19 [==============================] - 0s 6ms/step - loss: 0.4195 - mae: 0.5797 - val_loss: 0.3735 - val_mae: 0.5393
    Epoch 30/400
    19/19 [==============================] - 0s 6ms/step - loss: 0.4138 - mae: 0.5744 - val_loss: 0.3697 - val_mae: 0.5371
    Epoch 31/400
    19/19 [==============================] - 0s 5ms/step - loss: 0.4095 - mae: 0.5735 - val_loss: 0.3656 - val_mae: 0.5339
    Epoch 32/400
    19/19 [==============================] - 0s 6ms/step - loss: 0.4047 - mae: 0.5692 - val_loss: 0.3615 - val_mae: 0.5312
    Epoch 33/400
    19/19 [==============================] - 0s 6ms/step - loss: 0.3974 - mae: 0.5637 - val_loss: 0.3601 - val_mae: 0.5292
    Epoch 34/400
    19/19 [==============================] - 0s 6ms/step - loss: 0.3966 - mae: 0.5649 - val_loss: 0.3535 - val_mae: 0.5254
    Epoch 35/400
    19/19 [==============================] - 0s 6ms/step - loss: 0.3884 - mae: 0.5577 - val_loss: 0.3484 - val_mae: 0.5212
    Epoch 36/400
    19/19 [==============================] - 0s 6ms/step - loss: 0.3837 - mae: 0.5547 - val_loss: 0.3456 - val_mae: 0.5192
    Epoch 37/400
    19/19 [==============================] - 0s 6ms/step - loss: 0.3782 - mae: 0.5507 - val_loss: 0.3393 - val_mae: 0.5144
    Epoch 38/400
    19/19 [==============================] - 0s 6ms/step - loss: 0.3731 - mae: 0.5468 - val_loss: 0.3347 - val_mae: 0.5111
    Epoch 39/400
    19/19 [==============================] - 0s 6ms/step - loss: 0.3678 - mae: 0.5427 - val_loss: 0.3300 - val_mae: 0.5076
    Epoch 40/400
    19/19 [==============================] - 0s 6ms/step - loss: 0.3615 - mae: 0.5385 - val_loss: 0.3257 - val_mae: 0.5040
    Epoch 41/400
    19/19 [==============================] - 0s 6ms/step - loss: 0.3558 - mae: 0.5331 - val_loss: 0.3212 - val_mae: 0.5010
    Epoch 42/400
    19/19 [==============================] - 0s 6ms/step - loss: 0.3489 - mae: 0.5279 - val_loss: 0.3146 - val_mae: 0.4958
    Epoch 43/400
    19/19 [==============================] - 0s 6ms/step - loss: 0.3430 - mae: 0.5240 - val_loss: 0.3092 - val_mae: 0.4915
    Epoch 44/400
    19/19 [==============================] - 0s 6ms/step - loss: 0.3385 - mae: 0.5206 - val_loss: 0.3049 - val_mae: 0.4878
    Epoch 45/400
    19/19 [==============================] - 0s 6ms/step - loss: 0.3315 - mae: 0.5144 - val_loss: 0.3033 - val_mae: 0.4860
    Epoch 46/400
    19/19 [==============================] - 0s 6ms/step - loss: 0.3268 - mae: 0.5115 - val_loss: 0.2959 - val_mae: 0.4811
    Epoch 47/400
    19/19 [==============================] - 0s 7ms/step - loss: 0.3205 - mae: 0.5045 - val_loss: 0.2910 - val_mae: 0.4771
    Epoch 48/400
    19/19 [==============================] - 0s 7ms/step - loss: 0.3141 - mae: 0.5020 - val_loss: 0.2864 - val_mae: 0.4732
    Epoch 49/400
    19/19 [==============================] - 0s 7ms/step - loss: 0.3091 - mae: 0.4979 - val_loss: 0.2820 - val_mae: 0.4692
    Epoch 50/400
    19/19 [==============================] - 0s 7ms/step - loss: 0.3037 - mae: 0.4921 - val_loss: 0.2756 - val_mae: 0.4641
    Epoch 51/400
    19/19 [==============================] - 0s 7ms/step - loss: 0.2973 - mae: 0.4870 - val_loss: 0.2770 - val_mae: 0.4628
    Epoch 52/400
    19/19 [==============================] - 0s 7ms/step - loss: 0.2895 - mae: 0.4802 - val_loss: 0.2703 - val_mae: 0.4568
    Epoch 53/400
    19/19 [==============================] - 0s 7ms/step - loss: 0.2838 - mae: 0.4740 - val_loss: 0.2620 - val_mae: 0.4517
    Epoch 54/400
    19/19 [==============================] - 0s 7ms/step - loss: 0.2790 - mae: 0.4709 - val_loss: 0.2537 - val_mae: 0.4452
    Epoch 55/400
    19/19 [==============================] - 0s 7ms/step - loss: 0.2721 - mae: 0.4664 - val_loss: 0.2488 - val_mae: 0.4406
    Epoch 56/400
    19/19 [==============================] - 0s 7ms/step - loss: 0.2662 - mae: 0.4609 - val_loss: 0.2434 - val_mae: 0.4359
    Epoch 57/400
    19/19 [==============================] - 0s 7ms/step - loss: 0.2599 - mae: 0.4551 - val_loss: 0.2385 - val_mae: 0.4312
    Epoch 58/400
    19/19 [==============================] - 0s 7ms/step - loss: 0.2516 - mae: 0.4472 - val_loss: 0.2333 - val_mae: 0.4258
    Epoch 59/400
    19/19 [==============================] - 0s 8ms/step - loss: 0.2469 - mae: 0.4429 - val_loss: 0.2262 - val_mae: 0.4198
    Epoch 60/400
    19/19 [==============================] - 0s 7ms/step - loss: 0.2388 - mae: 0.4355 - val_loss: 0.2217 - val_mae: 0.4149
    Epoch 61/400
    19/19 [==============================] - 0s 8ms/step - loss: 0.2333 - mae: 0.4301 - val_loss: 0.2147 - val_mae: 0.4088
    Epoch 62/400
    19/19 [==============================] - 0s 7ms/step - loss: 0.2247 - mae: 0.4215 - val_loss: 0.2206 - val_mae: 0.4081
    Epoch 63/400
    19/19 [==============================] - 0s 8ms/step - loss: 0.2204 - mae: 0.4172 - val_loss: 0.2050 - val_mae: 0.3985
    Epoch 64/400
    19/19 [==============================] - 0s 7ms/step - loss: 0.2134 - mae: 0.4116 - val_loss: 0.2003 - val_mae: 0.3931
    Epoch 65/400
    19/19 [==============================] - 0s 7ms/step - loss: 0.2063 - mae: 0.4027 - val_loss: 0.1915 - val_mae: 0.3857
    Epoch 66/400
    19/19 [==============================] - 0s 7ms/step - loss: 0.2011 - mae: 0.3998 - val_loss: 0.1860 - val_mae: 0.3802
    Epoch 67/400
    19/19 [==============================] - 0s 7ms/step - loss: 0.1945 - mae: 0.3926 - val_loss: 0.1805 - val_mae: 0.3744
    Epoch 68/400
    19/19 [==============================] - 0s 8ms/step - loss: 0.1886 - mae: 0.3860 - val_loss: 0.1753 - val_mae: 0.3686
    Epoch 69/400
    19/19 [==============================] - 0s 7ms/step - loss: 0.1820 - mae: 0.3784 - val_loss: 0.1719 - val_mae: 0.3637
    Epoch 70/400
    19/19 [==============================] - 0s 8ms/step - loss: 0.1775 - mae: 0.3736 - val_loss: 0.1659 - val_mae: 0.3579
    Epoch 71/400
    19/19 [==============================] - 0s 7ms/step - loss: 0.1699 - mae: 0.3660 - val_loss: 0.1615 - val_mae: 0.3516
    Epoch 72/400
    19/19 [==============================] - 0s 7ms/step - loss: 0.1655 - mae: 0.3611 - val_loss: 0.1559 - val_mae: 0.3464
    Epoch 73/400
    19/19 [==============================] - 0s 7ms/step - loss: 0.1591 - mae: 0.3538 - val_loss: 0.1498 - val_mae: 0.3398
    Epoch 74/400
    19/19 [==============================] - 0s 7ms/step - loss: 0.1541 - mae: 0.3473 - val_loss: 0.1461 - val_mae: 0.3347
    Epoch 75/400
    19/19 [==============================] - 0s 7ms/step - loss: 0.1487 - mae: 0.3417 - val_loss: 0.1395 - val_mae: 0.3278
    Epoch 76/400
    19/19 [==============================] - 0s 8ms/step - loss: 0.1414 - mae: 0.3303 - val_loss: 0.1342 - val_mae: 0.3212
    Epoch 77/400
    19/19 [==============================] - 0s 7ms/step - loss: 0.1364 - mae: 0.3247 - val_loss: 0.1297 - val_mae: 0.3149
    Epoch 78/400
    19/19 [==============================] - 0s 8ms/step - loss: 0.1316 - mae: 0.3194 - val_loss: 0.1256 - val_mae: 0.3092
    Epoch 79/400
    19/19 [==============================] - 0s 7ms/step - loss: 0.1261 - mae: 0.3131 - val_loss: 0.1202 - val_mae: 0.3025
    Epoch 80/400
    19/19 [==============================] - 0s 7ms/step - loss: 0.1209 - mae: 0.3056 - val_loss: 0.1167 - val_mae: 0.2968
    Epoch 81/400
    19/19 [==============================] - 0s 8ms/step - loss: 0.1157 - mae: 0.2991 - val_loss: 0.1103 - val_mae: 0.2895
    Epoch 82/400
    19/19 [==============================] - 0s 7ms/step - loss: 0.1104 - mae: 0.2911 - val_loss: 0.1055 - val_mae: 0.2829
    Epoch 83/400
    19/19 [==============================] - 0s 7ms/step - loss: 0.1056 - mae: 0.2849 - val_loss: 0.1040 - val_mae: 0.2782
    Epoch 84/400
    19/19 [==============================] - 0s 7ms/step - loss: 0.1008 - mae: 0.2769 - val_loss: 0.0963 - val_mae: 0.2699
    Epoch 85/400
    19/19 [==============================] - 0s 7ms/step - loss: 0.0965 - mae: 0.2716 - val_loss: 0.0925 - val_mae: 0.2637
    Epoch 86/400
    19/19 [==============================] - 0s 7ms/step - loss: 0.0915 - mae: 0.2624 - val_loss: 0.0903 - val_mae: 0.2585
    Epoch 87/400
    19/19 [==============================] - 0s 7ms/step - loss: 0.0877 - mae: 0.2579 - val_loss: 0.0844 - val_mae: 0.2515
    Epoch 88/400
    19/19 [==============================] - 0s 7ms/step - loss: 0.0843 - mae: 0.2523 - val_loss: 0.0836 - val_mae: 0.2476
    Epoch 89/400
    19/19 [==============================] - 0s 7ms/step - loss: 0.0786 - mae: 0.2428 - val_loss: 0.0800 - val_mae: 0.2415
    Epoch 90/400
    19/19 [==============================] - 0s 8ms/step - loss: 0.0740 - mae: 0.2345 - val_loss: 0.0724 - val_mae: 0.2313
    Epoch 91/400
    19/19 [==============================] - 0s 7ms/step - loss: 0.0706 - mae: 0.2269 - val_loss: 0.0684 - val_mae: 0.2247
    Epoch 92/400
    19/19 [==============================] - 0s 7ms/step - loss: 0.0670 - mae: 0.2231 - val_loss: 0.0664 - val_mae: 0.2187
    Epoch 93/400
    19/19 [==============================] - 0s 8ms/step - loss: 0.0630 - mae: 0.2148 - val_loss: 0.0639 - val_mae: 0.2131
    Epoch 94/400
    19/19 [==============================] - 0s 7ms/step - loss: 0.0593 - mae: 0.2076 - val_loss: 0.0580 - val_mae: 0.2056
    Epoch 95/400
    19/19 [==============================] - 0s 8ms/step - loss: 0.0566 - mae: 0.2021 - val_loss: 0.0550 - val_mae: 0.1994
    Epoch 96/400
    19/19 [==============================] - 0s 7ms/step - loss: 0.0533 - mae: 0.1956 - val_loss: 0.0532 - val_mae: 0.1951
    Epoch 97/400
    19/19 [==============================] - 0s 7ms/step - loss: 0.0492 - mae: 0.1876 - val_loss: 0.0489 - val_mae: 0.1863
    Epoch 98/400
    19/19 [==============================] - 0s 8ms/step - loss: 0.0460 - mae: 0.1808 - val_loss: 0.0490 - val_mae: 0.1860
    Epoch 99/400
    19/19 [==============================] - 0s 8ms/step - loss: 0.0434 - mae: 0.1759 - val_loss: 0.0431 - val_mae: 0.1748
    Epoch 100/400
    19/19 [==============================] - 0s 7ms/step - loss: 0.0416 - mae: 0.1710 - val_loss: 0.0410 - val_mae: 0.1688
    Epoch 101/400
    19/19 [==============================] - 0s 7ms/step - loss: 0.0386 - mae: 0.1646 - val_loss: 0.0384 - val_mae: 0.1635
    Epoch 102/400
    19/19 [==============================] - 0s 8ms/step - loss: 0.0366 - mae: 0.1584 - val_loss: 0.0390 - val_mae: 0.1626
    Epoch 103/400
    19/19 [==============================] - 0s 8ms/step - loss: 0.0350 - mae: 0.1565 - val_loss: 0.0343 - val_mae: 0.1544
    Epoch 104/400
    19/19 [==============================] - 0s 8ms/step - loss: 0.0330 - mae: 0.1517 - val_loss: 0.0327 - val_mae: 0.1504
    Epoch 105/400
    19/19 [==============================] - 0s 7ms/step - loss: 0.0315 - mae: 0.1470 - val_loss: 0.0319 - val_mae: 0.1478
    Epoch 106/400
    19/19 [==============================] - 0s 8ms/step - loss: 0.0302 - mae: 0.1442 - val_loss: 0.0296 - val_mae: 0.1429
    Epoch 107/400
    19/19 [==============================] - 0s 7ms/step - loss: 0.0292 - mae: 0.1419 - val_loss: 0.0281 - val_mae: 0.1392
    Epoch 108/400
    19/19 [==============================] - 0s 7ms/step - loss: 0.0276 - mae: 0.1373 - val_loss: 0.0267 - val_mae: 0.1355
    Epoch 109/400
    19/19 [==============================] - 0s 7ms/step - loss: 0.0267 - mae: 0.1338 - val_loss: 0.0264 - val_mae: 0.1342
    Epoch 110/400
    19/19 [==============================] - 0s 7ms/step - loss: 0.0251 - mae: 0.1304 - val_loss: 0.0268 - val_mae: 0.1356
    Epoch 111/400
    19/19 [==============================] - 0s 8ms/step - loss: 0.0248 - mae: 0.1295 - val_loss: 0.0243 - val_mae: 0.1289
    Epoch 112/400
    19/19 [==============================] - 0s 7ms/step - loss: 0.0238 - mae: 0.1265 - val_loss: 0.0262 - val_mae: 0.1315
    Epoch 113/400
    19/19 [==============================] - 0s 8ms/step - loss: 0.0236 - mae: 0.1263 - val_loss: 0.0221 - val_mae: 0.1229
    Epoch 114/400
    19/19 [==============================] - 0s 7ms/step - loss: 0.0222 - mae: 0.1204 - val_loss: 0.0219 - val_mae: 0.1223
    Epoch 115/400
    19/19 [==============================] - 0s 7ms/step - loss: 0.0214 - mae: 0.1201 - val_loss: 0.0221 - val_mae: 0.1229
    Epoch 116/400
    19/19 [==============================] - 0s 8ms/step - loss: 0.0211 - mae: 0.1184 - val_loss: 0.0215 - val_mae: 0.1212
    Epoch 117/400
    19/19 [==============================] - 0s 7ms/step - loss: 0.0208 - mae: 0.1176 - val_loss: 0.0222 - val_mae: 0.1229
    Epoch 118/400
    19/19 [==============================] - 0s 8ms/step - loss: 0.0205 - mae: 0.1166 - val_loss: 0.0190 - val_mae: 0.1134
    Epoch 119/400
    19/19 [==============================] - 0s 7ms/step - loss: 0.0205 - mae: 0.1144 - val_loss: 0.0199 - val_mae: 0.1163
    Epoch 120/400
    19/19 [==============================] - 0s 7ms/step - loss: 0.0195 - mae: 0.1110 - val_loss: 0.0193 - val_mae: 0.1119
    Epoch 121/400
    19/19 [==============================] - 0s 7ms/step - loss: 0.0194 - mae: 0.1110 - val_loss: 0.0181 - val_mae: 0.1098
    Epoch 122/400
    19/19 [==============================] - 0s 7ms/step - loss: 0.0193 - mae: 0.1105 - val_loss: 0.0180 - val_mae: 0.1086
    Epoch 123/400
    19/19 [==============================] - 0s 8ms/step - loss: 0.0191 - mae: 0.1101 - val_loss: 0.0185 - val_mae: 0.1118
    Epoch 124/400
    19/19 [==============================] - 0s 7ms/step - loss: 0.0185 - mae: 0.1094 - val_loss: 0.0196 - val_mae: 0.1150
    Epoch 125/400
    19/19 [==============================] - 0s 8ms/step - loss: 0.0189 - mae: 0.1103 - val_loss: 0.0178 - val_mae: 0.1097
    Epoch 126/400
    19/19 [==============================] - 0s 8ms/step - loss: 0.0184 - mae: 0.1076 - val_loss: 0.0165 - val_mae: 0.1047
    Epoch 127/400
    19/19 [==============================] - 0s 7ms/step - loss: 0.0185 - mae: 0.1080 - val_loss: 0.0165 - val_mae: 0.1049
    Epoch 128/400
    19/19 [==============================] - 0s 8ms/step - loss: 0.0176 - mae: 0.1064 - val_loss: 0.0162 - val_mae: 0.1037
    Epoch 129/400
    19/19 [==============================] - 0s 7ms/step - loss: 0.0183 - mae: 0.1080 - val_loss: 0.0165 - val_mae: 0.1032
    Epoch 130/400
    19/19 [==============================] - 0s 7ms/step - loss: 0.0178 - mae: 0.1052 - val_loss: 0.0157 - val_mae: 0.1019
    Epoch 131/400
    19/19 [==============================] - 0s 8ms/step - loss: 0.0172 - mae: 0.1056 - val_loss: 0.0216 - val_mae: 0.1191
    Epoch 132/400
    19/19 [==============================] - 0s 7ms/step - loss: 0.0177 - mae: 0.1071 - val_loss: 0.0181 - val_mae: 0.1101
    Epoch 133/400
    19/19 [==============================] - 0s 7ms/step - loss: 0.0172 - mae: 0.1042 - val_loss: 0.0154 - val_mae: 0.1005
    Epoch 134/400
    19/19 [==============================] - 0s 7ms/step - loss: 0.0170 - mae: 0.1035 - val_loss: 0.0152 - val_mae: 0.0997
    Epoch 135/400
    19/19 [==============================] - 0s 7ms/step - loss: 0.0171 - mae: 0.1034 - val_loss: 0.0166 - val_mae: 0.1020
    Epoch 136/400
    19/19 [==============================] - 0s 7ms/step - loss: 0.0167 - mae: 0.1021 - val_loss: 0.0150 - val_mae: 0.0992
    Epoch 137/400
    19/19 [==============================] - 0s 7ms/step - loss: 0.0177 - mae: 0.1057 - val_loss: 0.0162 - val_mae: 0.1042
    Epoch 138/400
    19/19 [==============================] - 0s 8ms/step - loss: 0.0176 - mae: 0.1064 - val_loss: 0.0151 - val_mae: 0.0991
    Epoch 139/400
    19/19 [==============================] - 0s 8ms/step - loss: 0.0166 - mae: 0.1024 - val_loss: 0.0148 - val_mae: 0.0980
    Epoch 140/400
    19/19 [==============================] - 0s 8ms/step - loss: 0.0169 - mae: 0.1033 - val_loss: 0.0147 - val_mae: 0.0982
    Epoch 141/400
    19/19 [==============================] - 0s 8ms/step - loss: 0.0172 - mae: 0.1047 - val_loss: 0.0147 - val_mae: 0.0983
    Epoch 142/400
    19/19 [==============================] - 0s 7ms/step - loss: 0.0167 - mae: 0.1038 - val_loss: 0.0155 - val_mae: 0.0991
    Epoch 143/400
    19/19 [==============================] - 0s 8ms/step - loss: 0.0170 - mae: 0.1032 - val_loss: 0.0247 - val_mae: 0.1269
    Epoch 144/400
    19/19 [==============================] - 0s 7ms/step - loss: 0.0167 - mae: 0.1014 - val_loss: 0.0146 - val_mae: 0.0975
    Epoch 145/400
    19/19 [==============================] - 0s 8ms/step - loss: 0.0168 - mae: 0.1031 - val_loss: 0.0153 - val_mae: 0.1007
    Epoch 146/400
    19/19 [==============================] - 0s 7ms/step - loss: 0.0168 - mae: 0.1029 - val_loss: 0.0202 - val_mae: 0.1122
    Epoch 147/400
    19/19 [==============================] - 0s 8ms/step - loss: 0.0166 - mae: 0.1033 - val_loss: 0.0221 - val_mae: 0.1198
    Epoch 148/400
    19/19 [==============================] - 0s 7ms/step - loss: 0.0166 - mae: 0.1025 - val_loss: 0.0202 - val_mae: 0.1150
    Epoch 149/400
    19/19 [==============================] - 0s 8ms/step - loss: 0.0172 - mae: 0.1033 - val_loss: 0.0152 - val_mae: 0.0979
    Epoch 150/400
    19/19 [==============================] - 0s 8ms/step - loss: 0.0171 - mae: 0.1035 - val_loss: 0.0154 - val_mae: 0.0984
    Epoch 151/400
    19/19 [==============================] - 0s 7ms/step - loss: 0.0164 - mae: 0.1021 - val_loss: 0.0141 - val_mae: 0.0962
    Epoch 152/400
    19/19 [==============================] - 0s 7ms/step - loss: 0.0166 - mae: 0.1026 - val_loss: 0.0158 - val_mae: 0.1023
    Epoch 153/400
    19/19 [==============================] - 0s 7ms/step - loss: 0.0167 - mae: 0.1027 - val_loss: 0.0145 - val_mae: 0.0976
    Epoch 154/400
    19/19 [==============================] - 0s 8ms/step - loss: 0.0167 - mae: 0.1031 - val_loss: 0.0141 - val_mae: 0.0957
    Epoch 155/400
    19/19 [==============================] - 0s 7ms/step - loss: 0.0173 - mae: 0.1041 - val_loss: 0.0151 - val_mae: 0.0974
    Epoch 156/400
    19/19 [==============================] - 0s 8ms/step - loss: 0.0167 - mae: 0.1035 - val_loss: 0.0160 - val_mae: 0.1031
    Epoch 157/400
    19/19 [==============================] - 0s 7ms/step - loss: 0.0162 - mae: 0.1015 - val_loss: 0.0144 - val_mae: 0.0972
    Epoch 158/400
    19/19 [==============================] - 0s 7ms/step - loss: 0.0173 - mae: 0.1031 - val_loss: 0.0140 - val_mae: 0.0954
    Epoch 159/400
    19/19 [==============================] - 0s 7ms/step - loss: 0.0162 - mae: 0.1010 - val_loss: 0.0167 - val_mae: 0.1051
    Epoch 160/400
    19/19 [==============================] - 0s 7ms/step - loss: 0.0170 - mae: 0.1037 - val_loss: 0.0141 - val_mae: 0.0964
    Epoch 161/400
    19/19 [==============================] - 0s 8ms/step - loss: 0.0164 - mae: 0.1012 - val_loss: 0.0155 - val_mae: 0.1013
    Epoch 162/400
    19/19 [==============================] - 0s 7ms/step - loss: 0.0170 - mae: 0.1037 - val_loss: 0.0152 - val_mae: 0.1004
    Epoch 163/400
    19/19 [==============================] - 0s 8ms/step - loss: 0.0167 - mae: 0.1019 - val_loss: 0.0140 - val_mae: 0.0958
    Epoch 164/400
    19/19 [==============================] - 0s 7ms/step - loss: 0.0169 - mae: 0.1027 - val_loss: 0.0144 - val_mae: 0.0961
    Epoch 165/400
    19/19 [==============================] - 0s 8ms/step - loss: 0.0166 - mae: 0.1028 - val_loss: 0.0142 - val_mae: 0.0959
    Epoch 166/400
    19/19 [==============================] - 0s 7ms/step - loss: 0.0162 - mae: 0.1015 - val_loss: 0.0146 - val_mae: 0.0980
    Epoch 167/400
    19/19 [==============================] - 0s 7ms/step - loss: 0.0165 - mae: 0.1016 - val_loss: 0.0156 - val_mae: 0.1017
    Epoch 168/400
    19/19 [==============================] - 0s 7ms/step - loss: 0.0167 - mae: 0.1030 - val_loss: 0.0147 - val_mae: 0.0962
    Epoch 169/400
    19/19 [==============================] - 0s 8ms/step - loss: 0.0171 - mae: 0.1045 - val_loss: 0.0139 - val_mae: 0.0949
    Epoch 170/400
    19/19 [==============================] - 0s 7ms/step - loss: 0.0163 - mae: 0.1014 - val_loss: 0.0147 - val_mae: 0.0983
    Epoch 171/400
    19/19 [==============================] - 0s 7ms/step - loss: 0.0172 - mae: 0.1042 - val_loss: 0.0139 - val_mae: 0.0949
    Epoch 172/400
    19/19 [==============================] - 0s 7ms/step - loss: 0.0166 - mae: 0.1018 - val_loss: 0.0166 - val_mae: 0.1046
    Epoch 173/400
    19/19 [==============================] - 0s 8ms/step - loss: 0.0169 - mae: 0.1039 - val_loss: 0.0151 - val_mae: 0.0969
    Epoch 174/400
    19/19 [==============================] - 0s 7ms/step - loss: 0.0166 - mae: 0.1032 - val_loss: 0.0139 - val_mae: 0.0949
    Epoch 175/400
    19/19 [==============================] - 0s 7ms/step - loss: 0.0165 - mae: 0.1007 - val_loss: 0.0140 - val_mae: 0.0957
    Epoch 176/400
    19/19 [==============================] - 0s 7ms/step - loss: 0.0170 - mae: 0.1034 - val_loss: 0.0138 - val_mae: 0.0948
    Epoch 177/400
    19/19 [==============================] - 0s 8ms/step - loss: 0.0162 - mae: 0.1017 - val_loss: 0.0147 - val_mae: 0.0960
    Epoch 178/400
    19/19 [==============================] - 0s 7ms/step - loss: 0.0168 - mae: 0.1033 - val_loss: 0.0143 - val_mae: 0.0952
    Epoch 179/400
    19/19 [==============================] - 0s 7ms/step - loss: 0.0166 - mae: 0.1020 - val_loss: 0.0152 - val_mae: 0.1004
    Epoch 180/400
    19/19 [==============================] - 0s 7ms/step - loss: 0.0175 - mae: 0.1062 - val_loss: 0.0139 - val_mae: 0.0946
    Epoch 181/400
    19/19 [==============================] - 0s 7ms/step - loss: 0.0165 - mae: 0.1011 - val_loss: 0.0166 - val_mae: 0.1046
    Epoch 182/400
    19/19 [==============================] - 0s 7ms/step - loss: 0.0167 - mae: 0.1019 - val_loss: 0.0150 - val_mae: 0.0995
    Epoch 183/400
    19/19 [==============================] - 0s 8ms/step - loss: 0.0161 - mae: 0.1013 - val_loss: 0.0157 - val_mae: 0.1018
    Epoch 184/400
    19/19 [==============================] - 0s 8ms/step - loss: 0.0169 - mae: 0.1021 - val_loss: 0.0158 - val_mae: 0.1022
    Epoch 185/400
    19/19 [==============================] - 0s 9ms/step - loss: 0.0170 - mae: 0.1037 - val_loss: 0.0144 - val_mae: 0.0955
    Epoch 186/400
    19/19 [==============================] - 0s 9ms/step - loss: 0.0166 - mae: 0.1021 - val_loss: 0.0142 - val_mae: 0.0948
    Epoch 187/400
    19/19 [==============================] - 0s 9ms/step - loss: 0.0165 - mae: 0.1025 - val_loss: 0.0159 - val_mae: 0.0993
    Epoch 188/400
    19/19 [==============================] - 0s 8ms/step - loss: 0.0169 - mae: 0.1026 - val_loss: 0.0140 - val_mae: 0.0946
    Epoch 189/400
    19/19 [==============================] - 0s 8ms/step - loss: 0.0174 - mae: 0.1056 - val_loss: 0.0143 - val_mae: 0.0967
    Epoch 190/400
    19/19 [==============================] - 0s 8ms/step - loss: 0.0167 - mae: 0.1021 - val_loss: 0.0180 - val_mae: 0.1082
    Epoch 191/400
    19/19 [==============================] - 0s 8ms/step - loss: 0.0171 - mae: 0.1027 - val_loss: 0.0159 - val_mae: 0.1025
    Epoch 192/400
    19/19 [==============================] - 0s 8ms/step - loss: 0.0170 - mae: 0.1041 - val_loss: 0.0143 - val_mae: 0.0952
    Epoch 193/400
    19/19 [==============================] - 0s 8ms/step - loss: 0.0162 - mae: 0.1012 - val_loss: 0.0140 - val_mae: 0.0946
    Epoch 194/400
    19/19 [==============================] - 0s 9ms/step - loss: 0.0164 - mae: 0.1016 - val_loss: 0.0178 - val_mae: 0.1044
    Epoch 195/400
    19/19 [==============================] - 0s 8ms/step - loss: 0.0168 - mae: 0.1020 - val_loss: 0.0141 - val_mae: 0.0946
    Epoch 196/400
    19/19 [==============================] - 0s 9ms/step - loss: 0.0163 - mae: 0.1027 - val_loss: 0.0182 - val_mae: 0.1089
    Epoch 197/400
    19/19 [==============================] - 0s 8ms/step - loss: 0.0171 - mae: 0.1030 - val_loss: 0.0145 - val_mae: 0.0977
    Epoch 198/400
    19/19 [==============================] - 0s 8ms/step - loss: 0.0162 - mae: 0.0998 - val_loss: 0.0137 - val_mae: 0.0948
    Epoch 199/400
    19/19 [==============================] - 0s 8ms/step - loss: 0.0167 - mae: 0.1016 - val_loss: 0.0170 - val_mae: 0.1056
    Epoch 200/400
    19/19 [==============================] - 0s 8ms/step - loss: 0.0165 - mae: 0.1020 - val_loss: 0.0149 - val_mae: 0.0963
    Epoch 201/400
    19/19 [==============================] - 0s 8ms/step - loss: 0.0170 - mae: 0.1031 - val_loss: 0.0145 - val_mae: 0.0955
    Epoch 202/400
    19/19 [==============================] - 0s 7ms/step - loss: 0.0168 - mae: 0.1027 - val_loss: 0.0152 - val_mae: 0.1002
    Epoch 203/400
    19/19 [==============================] - 0s 8ms/step - loss: 0.0168 - mae: 0.1033 - val_loss: 0.0138 - val_mae: 0.0950
    Epoch 204/400
    19/19 [==============================] - 0s 8ms/step - loss: 0.0169 - mae: 0.1023 - val_loss: 0.0141 - val_mae: 0.0962
    Epoch 205/400
    19/19 [==============================] - 0s 9ms/step - loss: 0.0167 - mae: 0.1018 - val_loss: 0.0138 - val_mae: 0.0951
    Epoch 206/400
    19/19 [==============================] - 0s 9ms/step - loss: 0.0157 - mae: 0.1005 - val_loss: 0.0148 - val_mae: 0.0986
    Epoch 207/400
    19/19 [==============================] - 0s 9ms/step - loss: 0.0169 - mae: 0.1033 - val_loss: 0.0141 - val_mae: 0.0945
    Epoch 208/400
    19/19 [==============================] - 0s 8ms/step - loss: 0.0166 - mae: 0.1025 - val_loss: 0.0148 - val_mae: 0.0987
    Epoch 209/400
    19/19 [==============================] - 0s 7ms/step - loss: 0.0160 - mae: 0.1000 - val_loss: 0.0176 - val_mae: 0.1039
    Epoch 210/400
    19/19 [==============================] - 0s 8ms/step - loss: 0.0168 - mae: 0.1024 - val_loss: 0.0155 - val_mae: 0.1010
    Epoch 211/400
    19/19 [==============================] - 0s 8ms/step - loss: 0.0163 - mae: 0.1011 - val_loss: 0.0160 - val_mae: 0.0994
    Epoch 212/400
    19/19 [==============================] - 0s 8ms/step - loss: 0.0161 - mae: 0.1000 - val_loss: 0.0139 - val_mae: 0.0942
    Epoch 213/400
    19/19 [==============================] - 0s 9ms/step - loss: 0.0166 - mae: 0.1021 - val_loss: 0.0154 - val_mae: 0.1010
    Epoch 214/400
    19/19 [==============================] - 0s 8ms/step - loss: 0.0164 - mae: 0.1023 - val_loss: 0.0137 - val_mae: 0.0943
    Epoch 215/400
    19/19 [==============================] - 0s 8ms/step - loss: 0.0162 - mae: 0.1009 - val_loss: 0.0138 - val_mae: 0.0944
    Epoch 216/400
    19/19 [==============================] - 0s 8ms/step - loss: 0.0166 - mae: 0.1014 - val_loss: 0.0138 - val_mae: 0.0950
    Epoch 217/400
    19/19 [==============================] - 0s 7ms/step - loss: 0.0161 - mae: 0.1001 - val_loss: 0.0136 - val_mae: 0.0938
    Epoch 218/400
    19/19 [==============================] - 0s 7ms/step - loss: 0.0168 - mae: 0.1032 - val_loss: 0.0137 - val_mae: 0.0947
    Epoch 219/400
    19/19 [==============================] - 0s 7ms/step - loss: 0.0162 - mae: 0.1019 - val_loss: 0.0135 - val_mae: 0.0941
    Epoch 220/400
    19/19 [==============================] - 0s 7ms/step - loss: 0.0161 - mae: 0.1008 - val_loss: 0.0155 - val_mae: 0.1014
    Epoch 221/400
    19/19 [==============================] - 0s 7ms/step - loss: 0.0157 - mae: 0.0994 - val_loss: 0.0174 - val_mae: 0.1073
    Epoch 222/400
    19/19 [==============================] - 0s 8ms/step - loss: 0.0162 - mae: 0.1004 - val_loss: 0.0137 - val_mae: 0.0935
    Epoch 223/400
    19/19 [==============================] - 0s 7ms/step - loss: 0.0166 - mae: 0.1026 - val_loss: 0.0182 - val_mae: 0.1096
    Epoch 224/400
    19/19 [==============================] - 0s 8ms/step - loss: 0.0155 - mae: 0.1000 - val_loss: 0.0159 - val_mae: 0.1025
    Epoch 225/400
    19/19 [==============================] - 0s 7ms/step - loss: 0.0159 - mae: 0.1007 - val_loss: 0.0148 - val_mae: 0.0954
    Epoch 226/400
    19/19 [==============================] - 0s 7ms/step - loss: 0.0157 - mae: 0.1002 - val_loss: 0.0157 - val_mae: 0.1022
    Epoch 227/400
    19/19 [==============================] - 0s 7ms/step - loss: 0.0155 - mae: 0.0987 - val_loss: 0.0127 - val_mae: 0.0914
    Epoch 228/400
    19/19 [==============================] - 0s 7ms/step - loss: 0.0162 - mae: 0.1006 - val_loss: 0.0140 - val_mae: 0.0967
    Epoch 229/400
    19/19 [==============================] - 0s 7ms/step - loss: 0.0154 - mae: 0.0994 - val_loss: 0.0128 - val_mae: 0.0914
    Epoch 230/400
    19/19 [==============================] - 0s 7ms/step - loss: 0.0151 - mae: 0.0982 - val_loss: 0.0133 - val_mae: 0.0916
    Epoch 231/400
    19/19 [==============================] - 0s 7ms/step - loss: 0.0160 - mae: 0.1014 - val_loss: 0.0141 - val_mae: 0.0968
    Epoch 232/400
    19/19 [==============================] - 0s 7ms/step - loss: 0.0154 - mae: 0.0989 - val_loss: 0.0127 - val_mae: 0.0903
    Epoch 233/400
    19/19 [==============================] - 0s 8ms/step - loss: 0.0147 - mae: 0.0967 - val_loss: 0.0126 - val_mae: 0.0904
    Epoch 234/400
    19/19 [==============================] - 0s 8ms/step - loss: 0.0152 - mae: 0.0984 - val_loss: 0.0132 - val_mae: 0.0932
    Epoch 235/400
    19/19 [==============================] - 0s 7ms/step - loss: 0.0149 - mae: 0.0967 - val_loss: 0.0144 - val_mae: 0.0938
    Epoch 236/400
    19/19 [==============================] - 0s 8ms/step - loss: 0.0151 - mae: 0.0983 - val_loss: 0.0125 - val_mae: 0.0899
    Epoch 237/400
    19/19 [==============================] - 0s 9ms/step - loss: 0.0146 - mae: 0.0957 - val_loss: 0.0130 - val_mae: 0.0923
    Epoch 238/400
    19/19 [==============================] - 0s 8ms/step - loss: 0.0147 - mae: 0.0967 - val_loss: 0.0124 - val_mae: 0.0893
    Epoch 239/400
    19/19 [==============================] - 0s 9ms/step - loss: 0.0146 - mae: 0.0967 - val_loss: 0.0128 - val_mae: 0.0900
    Epoch 240/400
    19/19 [==============================] - 0s 6ms/step - loss: 0.0142 - mae: 0.0956 - val_loss: 0.0123 - val_mae: 0.0893
    Epoch 241/400
    19/19 [==============================] - 0s 5ms/step - loss: 0.0150 - mae: 0.0973 - val_loss: 0.0151 - val_mae: 0.0997
    Epoch 242/400
    19/19 [==============================] - 0s 5ms/step - loss: 0.0144 - mae: 0.0962 - val_loss: 0.0171 - val_mae: 0.1063
    Epoch 243/400
    19/19 [==============================] - 0s 5ms/step - loss: 0.0153 - mae: 0.0979 - val_loss: 0.0177 - val_mae: 0.1081
    Epoch 244/400
    19/19 [==============================] - 0s 6ms/step - loss: 0.0146 - mae: 0.0949 - val_loss: 0.0124 - val_mae: 0.0898
    Epoch 245/400
    19/19 [==============================] - 0s 5ms/step - loss: 0.0152 - mae: 0.0970 - val_loss: 0.0127 - val_mae: 0.0911
    Epoch 246/400
    19/19 [==============================] - 0s 6ms/step - loss: 0.0146 - mae: 0.0969 - val_loss: 0.0128 - val_mae: 0.0893
    Epoch 247/400
    19/19 [==============================] - 0s 6ms/step - loss: 0.0151 - mae: 0.0981 - val_loss: 0.0139 - val_mae: 0.0956
    Epoch 248/400
    19/19 [==============================] - 0s 6ms/step - loss: 0.0150 - mae: 0.0976 - val_loss: 0.0145 - val_mae: 0.0979
    Epoch 249/400
    19/19 [==============================] - 0s 5ms/step - loss: 0.0146 - mae: 0.0956 - val_loss: 0.0132 - val_mae: 0.0901
    Epoch 250/400
    19/19 [==============================] - 0s 6ms/step - loss: 0.0148 - mae: 0.0976 - val_loss: 0.0122 - val_mae: 0.0890
    Epoch 251/400
    19/19 [==============================] - 0s 6ms/step - loss: 0.0142 - mae: 0.0946 - val_loss: 0.0140 - val_mae: 0.0956
    Epoch 252/400
    19/19 [==============================] - 0s 5ms/step - loss: 0.0148 - mae: 0.0965 - val_loss: 0.0124 - val_mae: 0.0893
    Epoch 253/400
    19/19 [==============================] - 0s 7ms/step - loss: 0.0145 - mae: 0.0955 - val_loss: 0.0130 - val_mae: 0.0898
    Epoch 254/400
    19/19 [==============================] - 0s 5ms/step - loss: 0.0146 - mae: 0.0956 - val_loss: 0.0124 - val_mae: 0.0898
    Epoch 255/400
    19/19 [==============================] - 0s 5ms/step - loss: 0.0147 - mae: 0.0958 - val_loss: 0.0123 - val_mae: 0.0890
    Epoch 256/400
    19/19 [==============================] - 0s 6ms/step - loss: 0.0146 - mae: 0.0963 - val_loss: 0.0123 - val_mae: 0.0894
    Epoch 257/400
    19/19 [==============================] - 0s 5ms/step - loss: 0.0145 - mae: 0.0968 - val_loss: 0.0131 - val_mae: 0.0925
    Epoch 258/400
    19/19 [==============================] - 0s 5ms/step - loss: 0.0150 - mae: 0.0978 - val_loss: 0.0123 - val_mae: 0.0894
    Epoch 259/400
    19/19 [==============================] - 0s 5ms/step - loss: 0.0144 - mae: 0.0961 - val_loss: 0.0123 - val_mae: 0.0881
    Epoch 260/400
    19/19 [==============================] - 0s 5ms/step - loss: 0.0136 - mae: 0.0935 - val_loss: 0.0123 - val_mae: 0.0885
    Epoch 261/400
    19/19 [==============================] - 0s 5ms/step - loss: 0.0147 - mae: 0.0967 - val_loss: 0.0126 - val_mae: 0.0905
    Epoch 262/400
    19/19 [==============================] - 0s 5ms/step - loss: 0.0146 - mae: 0.0952 - val_loss: 0.0123 - val_mae: 0.0894
    Epoch 263/400
    19/19 [==============================] - 0s 5ms/step - loss: 0.0146 - mae: 0.0953 - val_loss: 0.0143 - val_mae: 0.0968
    Epoch 264/400
    19/19 [==============================] - 0s 5ms/step - loss: 0.0145 - mae: 0.0952 - val_loss: 0.0139 - val_mae: 0.0953
    Epoch 265/400
    19/19 [==============================] - 0s 5ms/step - loss: 0.0145 - mae: 0.0964 - val_loss: 0.0122 - val_mae: 0.0892
    Epoch 266/400
    19/19 [==============================] - 0s 6ms/step - loss: 0.0140 - mae: 0.0946 - val_loss: 0.0126 - val_mae: 0.0882
    Epoch 267/400
    19/19 [==============================] - 0s 6ms/step - loss: 0.0141 - mae: 0.0942 - val_loss: 0.0162 - val_mae: 0.1031
    Epoch 268/400
    19/19 [==============================] - 0s 6ms/step - loss: 0.0146 - mae: 0.0956 - val_loss: 0.0122 - val_mae: 0.0892
    Epoch 269/400
    19/19 [==============================] - 0s 6ms/step - loss: 0.0137 - mae: 0.0923 - val_loss: 0.0120 - val_mae: 0.0878
    Epoch 270/400
    19/19 [==============================] - 0s 6ms/step - loss: 0.0151 - mae: 0.0974 - val_loss: 0.0121 - val_mae: 0.0887
    Epoch 271/400
    19/19 [==============================] - 0s 7ms/step - loss: 0.0143 - mae: 0.0952 - val_loss: 0.0127 - val_mae: 0.0911
    Epoch 272/400
    19/19 [==============================] - 0s 6ms/step - loss: 0.0141 - mae: 0.0947 - val_loss: 0.0156 - val_mae: 0.0967
    Epoch 273/400
    19/19 [==============================] - 0s 6ms/step - loss: 0.0151 - mae: 0.0969 - val_loss: 0.0120 - val_mae: 0.0879
    Epoch 274/400
    19/19 [==============================] - 0s 7ms/step - loss: 0.0139 - mae: 0.0935 - val_loss: 0.0120 - val_mae: 0.0881
    Epoch 275/400
    19/19 [==============================] - 0s 6ms/step - loss: 0.0147 - mae: 0.0965 - val_loss: 0.0119 - val_mae: 0.0875
    Epoch 276/400
    19/19 [==============================] - 0s 6ms/step - loss: 0.0139 - mae: 0.0935 - val_loss: 0.0118 - val_mae: 0.0872
    Epoch 277/400
    19/19 [==============================] - 0s 6ms/step - loss: 0.0150 - mae: 0.0979 - val_loss: 0.0119 - val_mae: 0.0878
    Epoch 278/400
    19/19 [==============================] - 0s 6ms/step - loss: 0.0145 - mae: 0.0950 - val_loss: 0.0120 - val_mae: 0.0880
    Epoch 279/400
    19/19 [==============================] - 0s 6ms/step - loss: 0.0140 - mae: 0.0939 - val_loss: 0.0121 - val_mae: 0.0874
    Epoch 280/400
    19/19 [==============================] - 0s 8ms/step - loss: 0.0146 - mae: 0.0964 - val_loss: 0.0121 - val_mae: 0.0886
    Epoch 281/400
    19/19 [==============================] - 0s 6ms/step - loss: 0.0144 - mae: 0.0945 - val_loss: 0.0128 - val_mae: 0.0913
    Epoch 282/400
    19/19 [==============================] - 0s 6ms/step - loss: 0.0147 - mae: 0.0974 - val_loss: 0.0121 - val_mae: 0.0882
    Epoch 283/400
    19/19 [==============================] - 0s 6ms/step - loss: 0.0142 - mae: 0.0934 - val_loss: 0.0117 - val_mae: 0.0869
    Epoch 284/400
    19/19 [==============================] - 0s 6ms/step - loss: 0.0146 - mae: 0.0969 - val_loss: 0.0134 - val_mae: 0.0934
    Epoch 285/400
    19/19 [==============================] - 0s 7ms/step - loss: 0.0142 - mae: 0.0940 - val_loss: 0.0176 - val_mae: 0.1073
    Epoch 286/400
    19/19 [==============================] - 0s 6ms/step - loss: 0.0147 - mae: 0.0963 - val_loss: 0.0161 - val_mae: 0.1025
    Epoch 287/400
    19/19 [==============================] - 0s 6ms/step - loss: 0.0142 - mae: 0.0947 - val_loss: 0.0131 - val_mae: 0.0922
    Epoch 288/400
    19/19 [==============================] - 0s 6ms/step - loss: 0.0150 - mae: 0.0962 - val_loss: 0.0179 - val_mae: 0.1080
    Epoch 289/400
    19/19 [==============================] - 0s 6ms/step - loss: 0.0149 - mae: 0.0968 - val_loss: 0.0138 - val_mae: 0.0947
    Epoch 290/400
    19/19 [==============================] - 0s 6ms/step - loss: 0.0141 - mae: 0.0936 - val_loss: 0.0127 - val_mae: 0.0907
    Epoch 291/400
    19/19 [==============================] - 0s 7ms/step - loss: 0.0141 - mae: 0.0942 - val_loss: 0.0152 - val_mae: 0.0953
    Epoch 292/400
    19/19 [==============================] - 0s 7ms/step - loss: 0.0143 - mae: 0.0947 - val_loss: 0.0148 - val_mae: 0.0941
    Epoch 293/400
    19/19 [==============================] - 0s 8ms/step - loss: 0.0149 - mae: 0.0987 - val_loss: 0.0120 - val_mae: 0.0878
    Epoch 294/400
    19/19 [==============================] - 0s 7ms/step - loss: 0.0142 - mae: 0.0938 - val_loss: 0.0125 - val_mae: 0.0900
    Epoch 295/400
    19/19 [==============================] - 0s 7ms/step - loss: 0.0145 - mae: 0.0949 - val_loss: 0.0118 - val_mae: 0.0872
    Epoch 296/400
    19/19 [==============================] - 0s 7ms/step - loss: 0.0135 - mae: 0.0931 - val_loss: 0.0151 - val_mae: 0.0994
    Epoch 297/400
    19/19 [==============================] - 0s 7ms/step - loss: 0.0146 - mae: 0.0967 - val_loss: 0.0133 - val_mae: 0.0931
    Epoch 298/400
    19/19 [==============================] - 0s 6ms/step - loss: 0.0145 - mae: 0.0966 - val_loss: 0.0117 - val_mae: 0.0868
    Epoch 299/400
    19/19 [==============================] - 0s 6ms/step - loss: 0.0138 - mae: 0.0926 - val_loss: 0.0130 - val_mae: 0.0886
    Epoch 300/400
    19/19 [==============================] - 0s 6ms/step - loss: 0.0143 - mae: 0.0954 - val_loss: 0.0122 - val_mae: 0.0886
    Epoch 301/400
    19/19 [==============================] - 0s 7ms/step - loss: 0.0141 - mae: 0.0951 - val_loss: 0.0127 - val_mae: 0.0882
    Epoch 302/400
    19/19 [==============================] - 0s 7ms/step - loss: 0.0146 - mae: 0.0964 - val_loss: 0.0122 - val_mae: 0.0871
    Epoch 303/400
    19/19 [==============================] - 0s 6ms/step - loss: 0.0140 - mae: 0.0940 - val_loss: 0.0118 - val_mae: 0.0872
    Epoch 304/400
    19/19 [==============================] - 0s 6ms/step - loss: 0.0142 - mae: 0.0948 - val_loss: 0.0146 - val_mae: 0.0973
    Epoch 305/400
    19/19 [==============================] - 0s 7ms/step - loss: 0.0142 - mae: 0.0949 - val_loss: 0.0135 - val_mae: 0.0901
    Epoch 306/400
    19/19 [==============================] - 0s 7ms/step - loss: 0.0144 - mae: 0.0946 - val_loss: 0.0131 - val_mae: 0.0921
    Epoch 307/400
    19/19 [==============================] - 0s 7ms/step - loss: 0.0146 - mae: 0.0969 - val_loss: 0.0162 - val_mae: 0.1028
    Epoch 308/400
    19/19 [==============================] - 0s 8ms/step - loss: 0.0142 - mae: 0.0948 - val_loss: 0.0118 - val_mae: 0.0870
    Epoch 309/400
    19/19 [==============================] - 0s 7ms/step - loss: 0.0139 - mae: 0.0939 - val_loss: 0.0121 - val_mae: 0.0866
    Epoch 310/400
    19/19 [==============================] - 0s 8ms/step - loss: 0.0143 - mae: 0.0942 - val_loss: 0.0119 - val_mae: 0.0877
    Epoch 311/400
    19/19 [==============================] - 0s 7ms/step - loss: 0.0146 - mae: 0.0947 - val_loss: 0.0128 - val_mae: 0.0909
    Epoch 312/400
    19/19 [==============================] - 0s 7ms/step - loss: 0.0141 - mae: 0.0945 - val_loss: 0.0119 - val_mae: 0.0871
    Epoch 313/400
    19/19 [==============================] - 0s 8ms/step - loss: 0.0138 - mae: 0.0948 - val_loss: 0.0118 - val_mae: 0.0871
    Epoch 314/400
    19/19 [==============================] - 0s 8ms/step - loss: 0.0140 - mae: 0.0943 - val_loss: 0.0149 - val_mae: 0.0945
    Epoch 315/400
    19/19 [==============================] - 0s 7ms/step - loss: 0.0141 - mae: 0.0943 - val_loss: 0.0149 - val_mae: 0.0986
    Epoch 316/400
    19/19 [==============================] - 0s 8ms/step - loss: 0.0146 - mae: 0.0964 - val_loss: 0.0119 - val_mae: 0.0875
    Epoch 317/400
    19/19 [==============================] - 0s 7ms/step - loss: 0.0150 - mae: 0.0960 - val_loss: 0.0126 - val_mae: 0.0876
    Epoch 318/400
    19/19 [==============================] - 0s 7ms/step - loss: 0.0143 - mae: 0.0952 - val_loss: 0.0118 - val_mae: 0.0868
    Epoch 319/400
    19/19 [==============================] - 0s 8ms/step - loss: 0.0143 - mae: 0.0947 - val_loss: 0.0119 - val_mae: 0.0869
    Epoch 320/400
    19/19 [==============================] - 0s 8ms/step - loss: 0.0144 - mae: 0.0944 - val_loss: 0.0135 - val_mae: 0.0900
    Epoch 321/400
    19/19 [==============================] - 0s 8ms/step - loss: 0.0140 - mae: 0.0924 - val_loss: 0.0164 - val_mae: 0.1038
    Epoch 322/400
    19/19 [==============================] - 0s 8ms/step - loss: 0.0142 - mae: 0.0955 - val_loss: 0.0119 - val_mae: 0.0871
    Epoch 323/400
    19/19 [==============================] - 0s 7ms/step - loss: 0.0139 - mae: 0.0924 - val_loss: 0.0146 - val_mae: 0.0974
    Epoch 324/400
    19/19 [==============================] - 0s 8ms/step - loss: 0.0141 - mae: 0.0951 - val_loss: 0.0119 - val_mae: 0.0870
    Epoch 325/400
    19/19 [==============================] - 0s 7ms/step - loss: 0.0145 - mae: 0.0952 - val_loss: 0.0123 - val_mae: 0.0892
    Epoch 326/400
    19/19 [==============================] - 0s 8ms/step - loss: 0.0139 - mae: 0.0933 - val_loss: 0.0144 - val_mae: 0.0967
    Epoch 327/400
    19/19 [==============================] - 0s 7ms/step - loss: 0.0142 - mae: 0.0946 - val_loss: 0.0119 - val_mae: 0.0869
    Epoch 328/400
    19/19 [==============================] - 0s 7ms/step - loss: 0.0147 - mae: 0.0960 - val_loss: 0.0121 - val_mae: 0.0882
    Epoch 329/400
    19/19 [==============================] - 0s 7ms/step - loss: 0.0140 - mae: 0.0945 - val_loss: 0.0119 - val_mae: 0.0874
    Epoch 330/400
    19/19 [==============================] - 0s 8ms/step - loss: 0.0145 - mae: 0.0957 - val_loss: 0.0173 - val_mae: 0.1064
    Epoch 331/400
    19/19 [==============================] - 0s 8ms/step - loss: 0.0142 - mae: 0.0939 - val_loss: 0.0119 - val_mae: 0.0865
    Epoch 332/400
    19/19 [==============================] - 0s 8ms/step - loss: 0.0142 - mae: 0.0953 - val_loss: 0.0122 - val_mae: 0.0886
    Epoch 333/400
    19/19 [==============================] - 0s 8ms/step - loss: 0.0141 - mae: 0.0955 - val_loss: 0.0147 - val_mae: 0.0978
    Epoch 334/400
    19/19 [==============================] - 0s 7ms/step - loss: 0.0141 - mae: 0.0951 - val_loss: 0.0144 - val_mae: 0.0966
    Epoch 335/400
    19/19 [==============================] - 0s 7ms/step - loss: 0.0137 - mae: 0.0934 - val_loss: 0.0118 - val_mae: 0.0870
    Epoch 336/400
    19/19 [==============================] - 0s 7ms/step - loss: 0.0141 - mae: 0.0951 - val_loss: 0.0120 - val_mae: 0.0869
    Epoch 337/400
    19/19 [==============================] - 0s 7ms/step - loss: 0.0138 - mae: 0.0935 - val_loss: 0.0121 - val_mae: 0.0873
    Epoch 338/400
    19/19 [==============================] - 0s 8ms/step - loss: 0.0143 - mae: 0.0948 - val_loss: 0.0133 - val_mae: 0.0929
    Epoch 339/400
    19/19 [==============================] - 0s 7ms/step - loss: 0.0142 - mae: 0.0944 - val_loss: 0.0117 - val_mae: 0.0865
    Epoch 340/400
    19/19 [==============================] - 0s 7ms/step - loss: 0.0143 - mae: 0.0951 - val_loss: 0.0222 - val_mae: 0.1206
    Epoch 341/400
    19/19 [==============================] - 0s 8ms/step - loss: 0.0144 - mae: 0.0942 - val_loss: 0.0122 - val_mae: 0.0886
    Epoch 342/400
    19/19 [==============================] - 0s 7ms/step - loss: 0.0140 - mae: 0.0936 - val_loss: 0.0132 - val_mae: 0.0927
    Epoch 343/400
    19/19 [==============================] - 0s 8ms/step - loss: 0.0143 - mae: 0.0948 - val_loss: 0.0124 - val_mae: 0.0873
    Epoch 344/400
    19/19 [==============================] - 0s 10ms/step - loss: 0.0143 - mae: 0.0947 - val_loss: 0.0119 - val_mae: 0.0874
    Epoch 345/400
    19/19 [==============================] - 0s 7ms/step - loss: 0.0142 - mae: 0.0951 - val_loss: 0.0123 - val_mae: 0.0890
    Epoch 346/400
    19/19 [==============================] - 0s 8ms/step - loss: 0.0142 - mae: 0.0939 - val_loss: 0.0151 - val_mae: 0.0992
    Epoch 347/400
    19/19 [==============================] - 0s 8ms/step - loss: 0.0144 - mae: 0.0951 - val_loss: 0.0132 - val_mae: 0.0927
    Epoch 348/400
    19/19 [==============================] - 0s 7ms/step - loss: 0.0142 - mae: 0.0948 - val_loss: 0.0123 - val_mae: 0.0889
    Epoch 349/400
    19/19 [==============================] - 0s 7ms/step - loss: 0.0141 - mae: 0.0945 - val_loss: 0.0120 - val_mae: 0.0868
    Epoch 350/400
    19/19 [==============================] - 0s 7ms/step - loss: 0.0137 - mae: 0.0929 - val_loss: 0.0165 - val_mae: 0.1035
    Epoch 351/400
    19/19 [==============================] - 0s 7ms/step - loss: 0.0146 - mae: 0.0965 - val_loss: 0.0122 - val_mae: 0.0887
    Epoch 352/400
    19/19 [==============================] - 0s 7ms/step - loss: 0.0136 - mae: 0.0930 - val_loss: 0.0127 - val_mae: 0.0906
    Epoch 353/400
    19/19 [==============================] - 0s 7ms/step - loss: 0.0146 - mae: 0.0951 - val_loss: 0.0137 - val_mae: 0.0943
    Epoch 354/400
    19/19 [==============================] - 0s 8ms/step - loss: 0.0144 - mae: 0.0942 - val_loss: 0.0122 - val_mae: 0.0887
    Epoch 355/400
    19/19 [==============================] - 0s 8ms/step - loss: 0.0139 - mae: 0.0942 - val_loss: 0.0119 - val_mae: 0.0877
    Epoch 356/400
    19/19 [==============================] - 0s 7ms/step - loss: 0.0142 - mae: 0.0939 - val_loss: 0.0128 - val_mae: 0.0912
    Epoch 357/400
    19/19 [==============================] - 0s 8ms/step - loss: 0.0145 - mae: 0.0942 - val_loss: 0.0116 - val_mae: 0.0864
    Epoch 358/400
    19/19 [==============================] - 0s 7ms/step - loss: 0.0137 - mae: 0.0926 - val_loss: 0.0130 - val_mae: 0.0916
    Epoch 359/400
    19/19 [==============================] - 0s 8ms/step - loss: 0.0143 - mae: 0.0956 - val_loss: 0.0117 - val_mae: 0.0866
    Epoch 360/400
    19/19 [==============================] - 0s 7ms/step - loss: 0.0136 - mae: 0.0921 - val_loss: 0.0181 - val_mae: 0.1085
    Epoch 361/400
    19/19 [==============================] - 0s 8ms/step - loss: 0.0146 - mae: 0.0951 - val_loss: 0.0141 - val_mae: 0.0956
    Epoch 362/400
    19/19 [==============================] - 0s 9ms/step - loss: 0.0144 - mae: 0.0949 - val_loss: 0.0121 - val_mae: 0.0884
    Epoch 363/400
    19/19 [==============================] - 0s 9ms/step - loss: 0.0143 - mae: 0.0944 - val_loss: 0.0151 - val_mae: 0.0990
    Epoch 364/400
    19/19 [==============================] - 0s 8ms/step - loss: 0.0141 - mae: 0.0938 - val_loss: 0.0137 - val_mae: 0.0909
    Epoch 365/400
    19/19 [==============================] - 0s 8ms/step - loss: 0.0142 - mae: 0.0947 - val_loss: 0.0143 - val_mae: 0.0926
    Epoch 366/400
    19/19 [==============================] - 0s 7ms/step - loss: 0.0138 - mae: 0.0928 - val_loss: 0.0119 - val_mae: 0.0869
    Epoch 367/400
    19/19 [==============================] - 0s 8ms/step - loss: 0.0143 - mae: 0.0939 - val_loss: 0.0119 - val_mae: 0.0867
    Epoch 368/400
    19/19 [==============================] - 0s 11ms/step - loss: 0.0143 - mae: 0.0941 - val_loss: 0.0143 - val_mae: 0.0964
    Epoch 369/400
    19/19 [==============================] - 0s 10ms/step - loss: 0.0144 - mae: 0.0953 - val_loss: 0.0120 - val_mae: 0.0866
    Epoch 370/400
    19/19 [==============================] - 0s 8ms/step - loss: 0.0144 - mae: 0.0949 - val_loss: 0.0117 - val_mae: 0.0867
    Epoch 371/400
    19/19 [==============================] - 0s 7ms/step - loss: 0.0141 - mae: 0.0938 - val_loss: 0.0120 - val_mae: 0.0879
    Epoch 372/400
    19/19 [==============================] - 0s 8ms/step - loss: 0.0141 - mae: 0.0930 - val_loss: 0.0118 - val_mae: 0.0861
    Epoch 373/400
    19/19 [==============================] - 0s 7ms/step - loss: 0.0147 - mae: 0.0958 - val_loss: 0.0118 - val_mae: 0.0872
    Epoch 374/400
    19/19 [==============================] - 0s 11ms/step - loss: 0.0138 - mae: 0.0936 - val_loss: 0.0118 - val_mae: 0.0872
    Epoch 375/400
    19/19 [==============================] - 0s 8ms/step - loss: 0.0142 - mae: 0.0942 - val_loss: 0.0121 - val_mae: 0.0883
    Epoch 376/400
    19/19 [==============================] - 0s 8ms/step - loss: 0.0134 - mae: 0.0922 - val_loss: 0.0157 - val_mae: 0.1011
    Epoch 377/400
    19/19 [==============================] - 0s 9ms/step - loss: 0.0140 - mae: 0.0936 - val_loss: 0.0129 - val_mae: 0.0886
    Epoch 378/400
    19/19 [==============================] - 0s 8ms/step - loss: 0.0145 - mae: 0.0950 - val_loss: 0.0161 - val_mae: 0.1023
    Epoch 379/400
    19/19 [==============================] - 0s 9ms/step - loss: 0.0147 - mae: 0.0961 - val_loss: 0.0118 - val_mae: 0.0868
    Epoch 380/400
    19/19 [==============================] - 0s 9ms/step - loss: 0.0145 - mae: 0.0954 - val_loss: 0.0169 - val_mae: 0.1005
    Epoch 381/400
    19/19 [==============================] - 0s 10ms/step - loss: 0.0140 - mae: 0.0935 - val_loss: 0.0168 - val_mae: 0.1048
    Epoch 382/400
    19/19 [==============================] - 0s 10ms/step - loss: 0.0145 - mae: 0.0947 - val_loss: 0.0155 - val_mae: 0.1004
    Epoch 383/400
    19/19 [==============================] - 0s 9ms/step - loss: 0.0139 - mae: 0.0937 - val_loss: 0.0125 - val_mae: 0.0873
    Epoch 384/400
    19/19 [==============================] - 0s 7ms/step - loss: 0.0144 - mae: 0.0955 - val_loss: 0.0119 - val_mae: 0.0876
    Epoch 385/400
    19/19 [==============================] - 0s 7ms/step - loss: 0.0144 - mae: 0.0950 - val_loss: 0.0117 - val_mae: 0.0866
    Epoch 386/400
    19/19 [==============================] - 0s 7ms/step - loss: 0.0137 - mae: 0.0932 - val_loss: 0.0121 - val_mae: 0.0867
    Epoch 387/400
    19/19 [==============================] - 0s 7ms/step - loss: 0.0139 - mae: 0.0938 - val_loss: 0.0116 - val_mae: 0.0863
    Epoch 388/400
    19/19 [==============================] - 0s 7ms/step - loss: 0.0145 - mae: 0.0946 - val_loss: 0.0123 - val_mae: 0.0871
    Epoch 389/400
    19/19 [==============================] - 0s 7ms/step - loss: 0.0143 - mae: 0.0945 - val_loss: 0.0133 - val_mae: 0.0927
    Epoch 390/400
    19/19 [==============================] - 0s 6ms/step - loss: 0.0144 - mae: 0.0944 - val_loss: 0.0138 - val_mae: 0.0945
    Epoch 391/400
    19/19 [==============================] - 0s 7ms/step - loss: 0.0139 - mae: 0.0941 - val_loss: 0.0121 - val_mae: 0.0866
    Epoch 392/400
    19/19 [==============================] - 0s 6ms/step - loss: 0.0142 - mae: 0.0954 - val_loss: 0.0122 - val_mae: 0.0867
    Epoch 393/400
    19/19 [==============================] - 0s 7ms/step - loss: 0.0143 - mae: 0.0951 - val_loss: 0.0117 - val_mae: 0.0868
    Epoch 394/400
    19/19 [==============================] - 0s 8ms/step - loss: 0.0136 - mae: 0.0929 - val_loss: 0.0151 - val_mae: 0.0990
    Epoch 395/400
    19/19 [==============================] - 0s 7ms/step - loss: 0.0149 - mae: 0.0958 - val_loss: 0.0124 - val_mae: 0.0871
    Epoch 396/400
    19/19 [==============================] - 0s 8ms/step - loss: 0.0143 - mae: 0.0944 - val_loss: 0.0130 - val_mae: 0.0886
    Epoch 397/400
    19/19 [==============================] - 0s 8ms/step - loss: 0.0135 - mae: 0.0921 - val_loss: 0.0128 - val_mae: 0.0912
    Epoch 398/400
    19/19 [==============================] - 0s 7ms/step - loss: 0.0141 - mae: 0.0943 - val_loss: 0.0219 - val_mae: 0.1202
    Epoch 399/400
    19/19 [==============================] - 0s 7ms/step - loss: 0.0150 - mae: 0.0954 - val_loss: 0.0118 - val_mae: 0.0870
    Epoch 400/400
    19/19 [==============================] - 0s 7ms/step - loss: 0.0144 - mae: 0.0952 - val_loss: 0.0163 - val_mae: 0.1031

### 3. Plot Metrics

**Loss (or Mean Squared Error)**

During training, the model's performance is constantly being measured against both our training data and the validation data that we set aside earlier.

Training produces a log of data that tells us how the model's performance changed over the course of the training process. The following cells will display some of that data in a graphical form:

```python
# Draw a graph of the loss, which is the distance between
# the predicted and actual values during training and validation.
#print(history_1.history.keys())

train_loss = history_1.history['loss']
val_loss = history_1.history['val_loss']

epochs = range(1, len(train_loss) + 1)

plt.plot(epochs, train_loss, 'g.', label='Training loss')
plt.plot(epochs, val_loss, 'b', label='Validation loss')
plt.title('Training and validation loss')
plt.xlabel('Epochs')
plt.ylabel('Loss')
plt.legend()
plt.show()
```

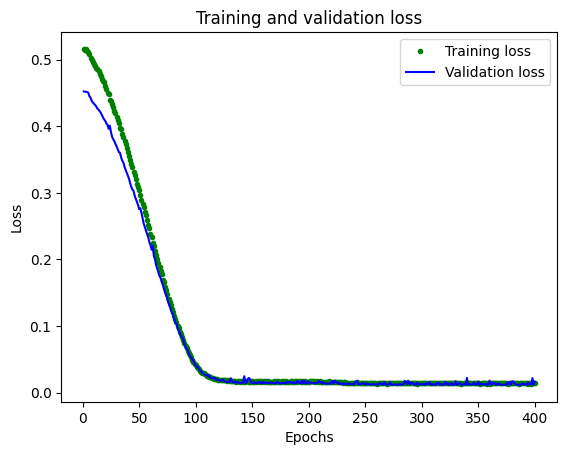
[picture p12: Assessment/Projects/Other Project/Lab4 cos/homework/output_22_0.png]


The graph shows the _loss_ (or the difference between the model's predictions and the actual data) for each epoch. There are several ways to calculate loss, and the method we have used is _mean squared error_. There is a distinct loss value given for the training and the validation data.

As we can see, the amount of loss rapidly decreases over the first 25 epochs, before flattening out. This means that the model is improving and producing more accurate predictions!

Our goal is to stop training when either the model is no longer improving, or when the _training loss_ is less than the _validation loss_, which would mean that the model has learned to predict the training data so well that it can no longer generalize to new data.

To make the flatter part of the graph more readable, let's skip the first 100 epochs:

```python
# Exclude the first few epochs so the graph is easier to read
SKIP = 100

plt.plot(epochs[SKIP:], train_loss[SKIP:], 'g.', label='Training loss')
plt.plot(epochs[SKIP:], val_loss[SKIP:], 'b.', label='Validation loss')
plt.title('Training and validation loss')
plt.xlabel('Epochs')
plt.ylabel('Loss')
plt.legend()
plt.show()
```

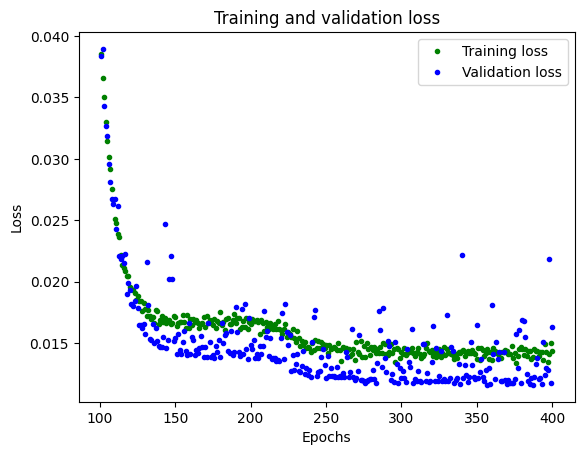
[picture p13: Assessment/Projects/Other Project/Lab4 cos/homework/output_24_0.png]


From the plot, we can see that loss continues to reduce until around 200 epochs, at which point it is mostly stable. This means that there's no need to train our network beyond 200 epochs.

However, we can also see that the lowest loss value is still around 0.155. This means that our network's predictions are off by an average of ~15%.

**2. Mean Absolute Error**

To gain more insight into our model's performance we can plot some more data. This time, we'll plot the _mean absolute error_, which is another way of measuring how far the network's predictions are from the actual numbers:

```python
plt.clf()

# Draw a graph of mean absolute error, which is another way of
# measuring the amount of error in the prediction.
train_mae = history_1.history['mae']
val_mae = history_1.history['val_mae']

plt.plot(epochs[SKIP:], train_mae[SKIP:], 'g.', label='Training MAE')
plt.plot(epochs[SKIP:], val_mae[SKIP:], 'b.', label='Validation MAE')
plt.title('Training and validation mean absolute error')
plt.xlabel('Epochs')
plt.ylabel('MAE')
plt.legend()
plt.show()
```

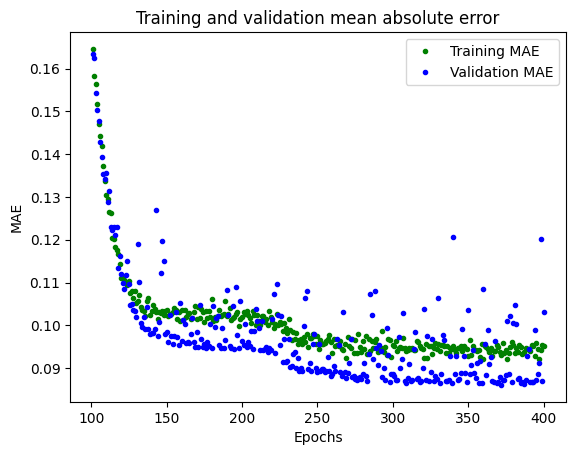
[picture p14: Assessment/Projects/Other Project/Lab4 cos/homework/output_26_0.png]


This graph of _mean absolute error_ tells another story. We can see that training data shows consistently lower error than validation data, which means that the network may have _overfit_, or learned the training data so rigidly that it can't make effective predictions about new data.

In addition, the mean absolute error values are quite high, >0.3 at best, which means some of the model's predictions are at least 30% off. A 30% error means we are very far from accurately modelling the sine wave function.

**3. Actual vs Predicted Outputs**

To get more insight into what is happening, let's check its predictions against the test dataset we set aside earlier:

```python
# Calculate and print the loss on our test dataset
test_loss, test_mae = model_1.evaluate(x_test, y_test)

# Make predictions based on our test dataset
y_test_pred = model_1.predict(x_test)

# Graph the predictions against the actual values
plt.clf()
plt.title('Comparison of predictions and actual values')
plt.plot(x_test, y_test, 'b.', label='Actual values')
plt.plot(x_test, y_test_pred, 'r.', label='TF predictions')
plt.legend()
plt.show()
```

    7/7 [==============================] - 0s 4ms/step - loss: 0.0162 - mae: 0.1001
    7/7 [==============================] - 0s 1ms/step

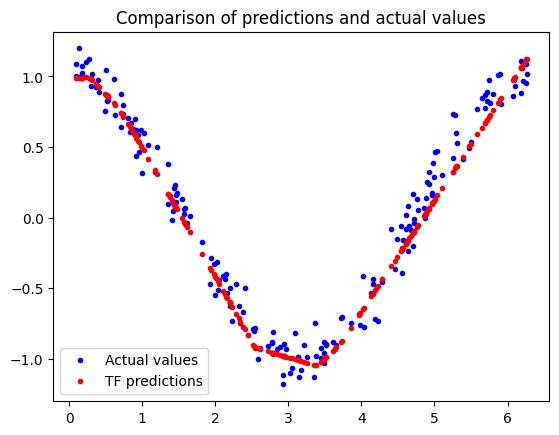
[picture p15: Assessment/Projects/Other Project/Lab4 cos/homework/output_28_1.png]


The graph makes it clear that our network has learned to approximate the sine function in a very limited way.

The rigidity of this fit suggests that the model does not have enough capacity to learn the full complexity of the sine wave function, so it's only able to approximate it in an overly simplistic way. By making our model bigger, we should be able to improve its performance.

## Training a Larger Model

### 1. Re-Design the Model
To make our model bigger, let's add an additional layer of neurons. The following cell redefines our model in the same way as earlier, but with 16 neurons in the first layer and an additional layer of 16 neurons in the middle:

```python
model = tf.keras.Sequential()

# First layer takes a scalar input and feeds it through 16 "neurons". The
# neurons decide whether to activate based on the 'relu' activation function.
model.add(keras.layers.Dense(16, activation='relu', input_shape=(1,)))

# The new second and third layer will help the network learn more complex representations
model.add(keras.layers.Dense(16, activation='relu'))

# Final layer is a single neuron, since we want to output a single value
model.add(keras.layers.Dense(1))

# Compile the model using the standard 'adam' optimizer and the mean squared error or 'mse' loss function for regression.
model.compile(optimizer='rmsprop', loss="mse", metrics=["mae"])
model.summary()
```

    Model: "sequential_1"
    _________________________________________________________________
     Layer (type)                Output Shape              Param #   
    =================================================================
     dense_2 (Dense)             (None, 16)                32        
                                                                     
     dense_3 (Dense)             (None, 16)                272       
                                                                     
     dense_4 (Dense)             (None, 1)                 17        
                                                                     
    =================================================================
    Total params: 321
    Trainable params: 321
    Non-trainable params: 0
    _________________________________________________________________

### 2. Re-Train the Model ###

We'll now train and save the new model.

```python
# Train the model
history = model.fit(x_train, y_train, epochs=500, batch_size=32,
                    validation_data=(x_validate, y_validate))
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

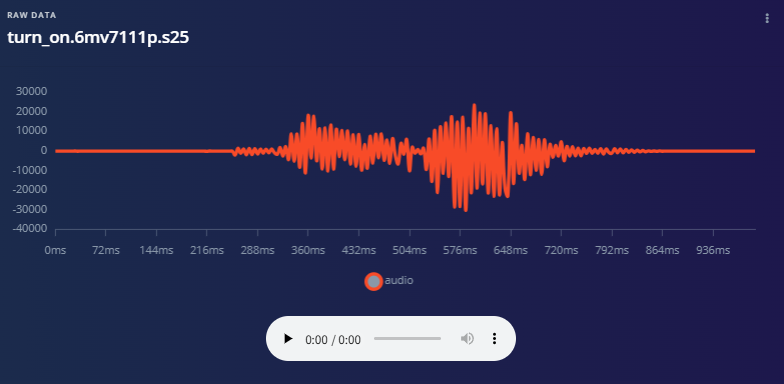
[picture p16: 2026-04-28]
Assessment/Projects/Final_Project/report_figures/01_data/turn_on.png

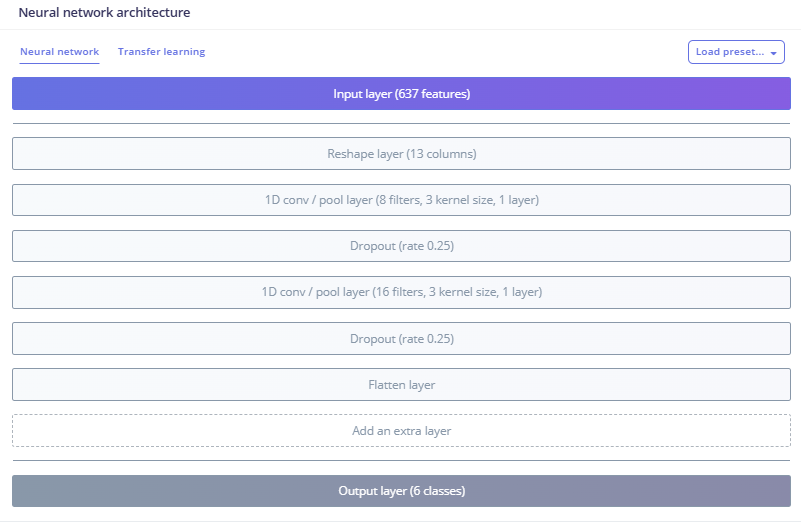
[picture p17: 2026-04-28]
Assessment/Projects/Final_Project/report_figures/03_experiments/baseline/baseline_architecture.png

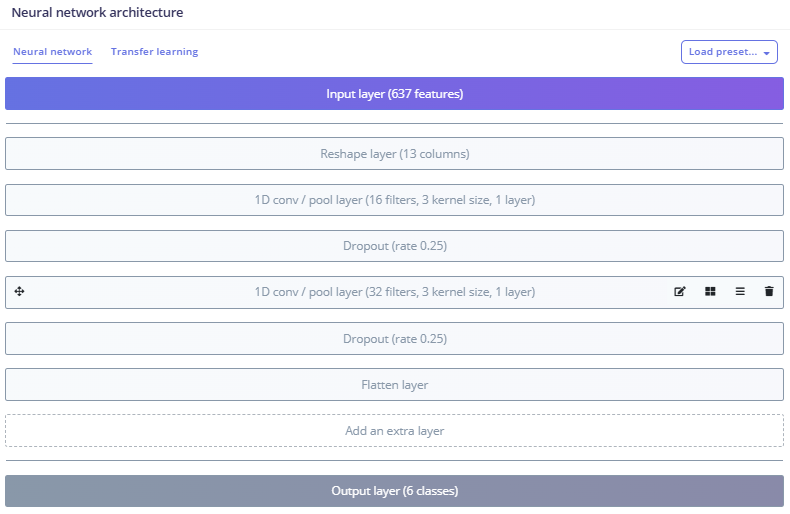
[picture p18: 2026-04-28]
Assessment/Projects/Final_Project/report_figures/03_experiments/exp_wider/wider_architecture.png

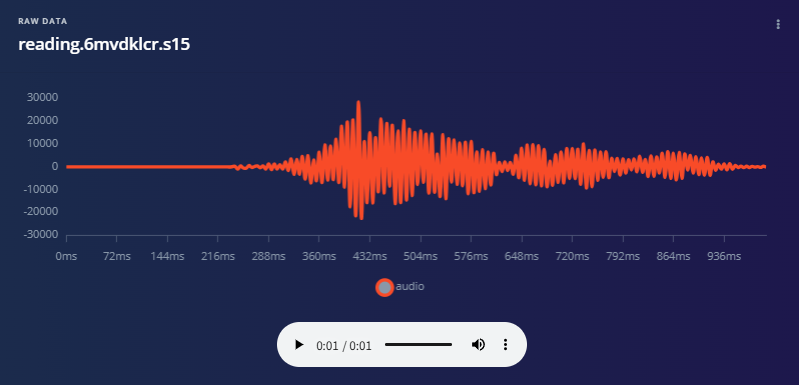
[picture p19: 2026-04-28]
Assessment/Projects/Final_Project/report_figures/01_data/reading.png

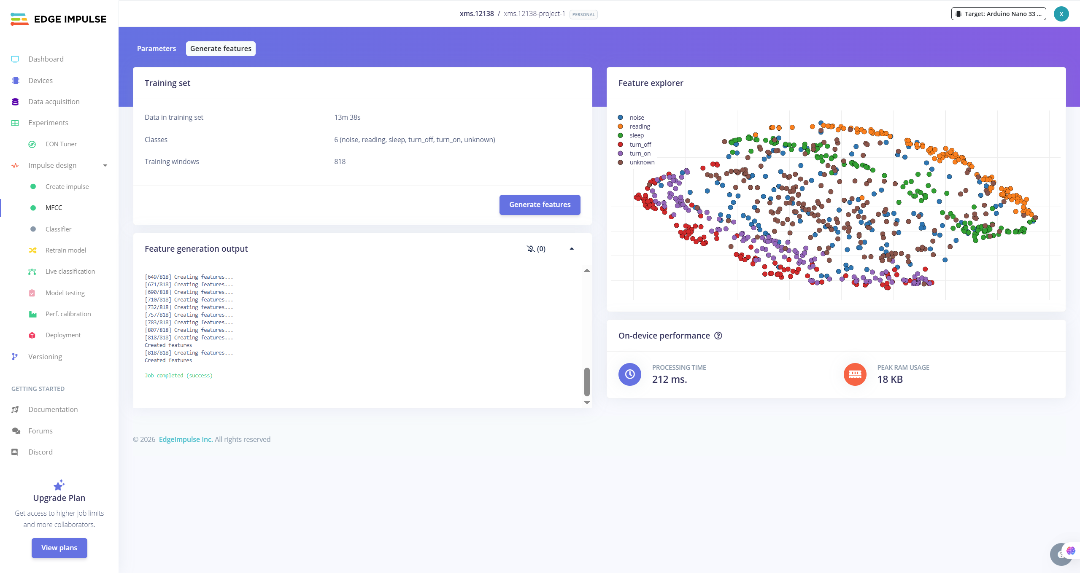
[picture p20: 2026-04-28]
Assessment/Projects/Final_Project/report_figures/02_methods/mfcc_feature_explorer.png

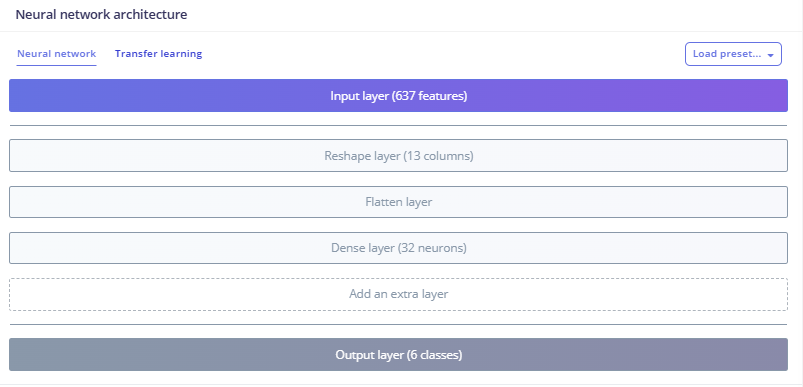
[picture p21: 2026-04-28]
Assessment/Projects/Final_Project/report_figures/03_experiments/exp_dense/dense_architecture.png

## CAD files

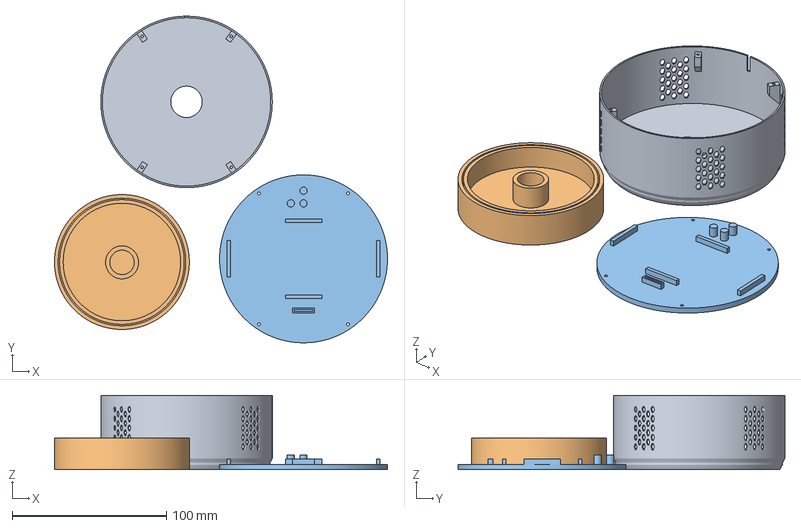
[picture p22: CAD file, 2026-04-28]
Assessment/Projects/Final_Project/3D_Printer/Base.3mf
215.8 x 211.7 x 48.3 mm
Base.stl
Lid 3.stl
Base Cover.stl

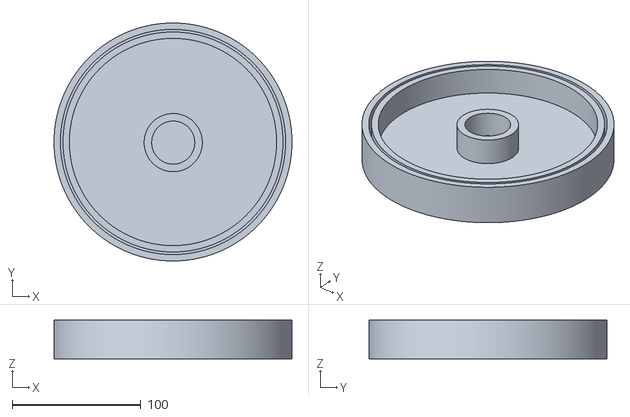
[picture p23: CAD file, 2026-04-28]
Assessment/Projects/Final_Project/3D_Printer/Lid 3.stl
185.0 x 185.0 x 30.0

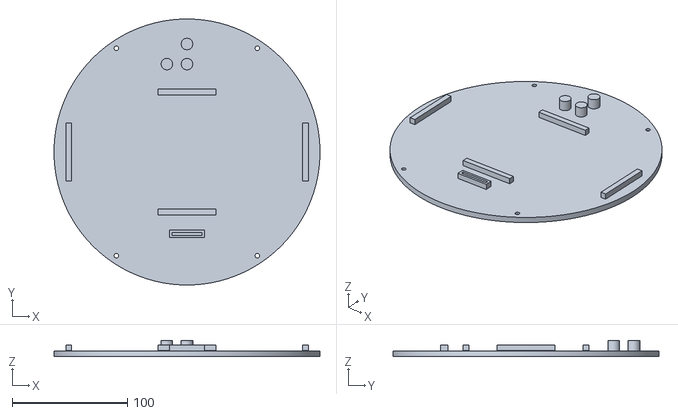
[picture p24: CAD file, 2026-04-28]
Assessment/Projects/Final_Project/3D_Printer/Base Cover.stl
230.4 x 230.4 x 13.9

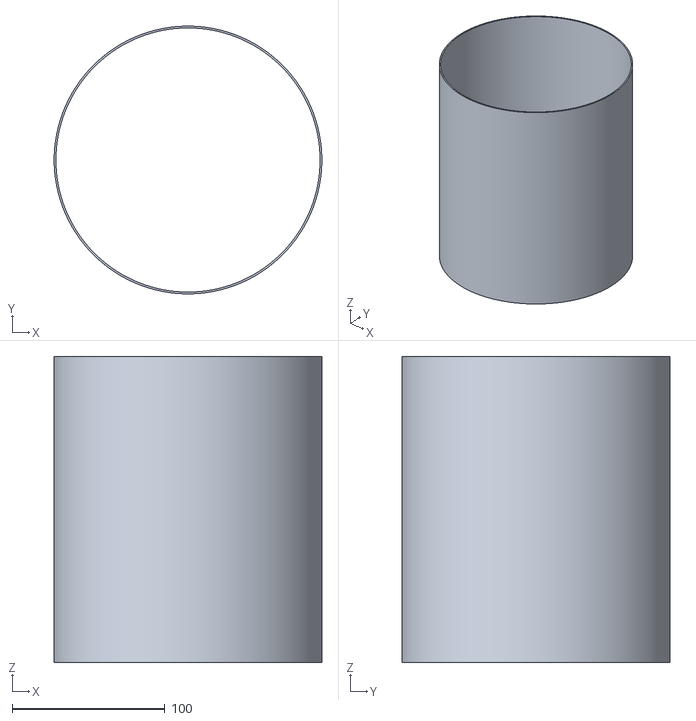
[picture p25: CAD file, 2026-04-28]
Assessment/Projects/Final_Project/3D_Printer/Diffuser.stl
175.0 x 175.0 x 200.0

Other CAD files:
Assessment/Projects/Final_Project/3D_Printer/Base.stl

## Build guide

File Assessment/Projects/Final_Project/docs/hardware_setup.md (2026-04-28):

# Hardware Setup

## Bill of Materials

| Item | Spec | Qty | Notes |
|---|---|---|---|
| Arduino Nano 33 BLE Sense | nRF52840, Cortex-M4F 64 MHz, 256 KB RAM, 1 MB Flash; onboard MP34DT05 PDM microphone | 1 | All inference and DSP run on this board. |
| WS2812B addressable LED strip | 5 V, GRB 800 kHz protocol; 10 LEDs (segment cut from a longer strip) | 1 | Driven from the Nano's 3.3 V rail (see *Power* below). |
| USB cable (Micro-USB) | Standard USB 2.0 | 1 | Powers the Nano from the host PC; the LED strip draws from the Nano's regulated rail. |
| 3D-printed enclosure | PLA, 4-part assembly (Base, Base Cover, Diffuser, Lid) | 1 set | STL/3MF in `3D_Printer/`. |

## Pin map

| Function | MCU pin | Connected to | Notes |
|---|---|---|---|
| WS2812B data in | D2 | Strip DIN | `LED_PIN = 2` in `arduino/echolume/echolume.ino`. |
| WS2812B power | 3.3 V | Strip VCC | Driven directly from the Nano's 3.3 V rail; see *Power* note. |
| WS2812B ground | GND | Strip GND | Common ground with MCU. |
| Microphone | onboard MP34DT05 | — | PDM, 16 kHz mono; no external wiring required. |

## Power

- The Nano 33 BLE Sense is powered over USB from a host PC.
- The 10-LED WS2812B segment is powered from the **Nano's 3.3 V rail**, not from a separate 5 V supply. WS2812B is nominally rated at 5 V but is driven reliably here at 3.3 V because (a) the strip is short (10 pixels), (b) brightness is software-capped via `strip.setBrightness(150)` (≈ 59 % of maximum) which lowers peak current per LED, and (c) operating from the same 3.3 V rail as the MCU keeps the data line within VIH at the first pixel without a level shifter.
- This is a deliberate simplicity choice for a desk demo. For a longer strip or for full-brightness white, a separate 5 V supply with a logic-level shifter on DIN would be required.

## Wiring

The full wiring is three jumpers from Nano → strip:

```
Nano 33 BLE Sense        WS2812B (10 LED)
---------------------    ----------------
D2  ────────────────────► DIN
3V3 ────────────────────► VCC
GND ────────────────────► GND
```

Photographs of the assembled hardware: `report_figures/05_hardware/` (4 images, captions TBD — to be matched against the actual views).

## 3D enclosure

Files (in `3D_Printer/`):

| File | Purpose |
|---|---|
| `Base.stl` / `Base.3mf` | Main housing for the Nano + strip |
| `Base Cover.stl` | Underside cover |
| `Diffuser.stl` | Translucent diffuser over the LED strip |
| `Lid 3.stl` | Top lid |
| `528071-3ft-led-tower-lamp-...pdf` | Source design reference (LED tower lamp) |

**Print parameters used (PLA):** 0.2 mm layer height, 15 % gyroid infill, default speed (≈ 50 mm/s), 3 perimeters, supports off for the diffuser to keep it translucent. Total print time ≈ several hours across the four parts.

The Diffuser is the only translucency-critical part; the rest are opaque structural. The 4-part split allows reprinting the Diffuser separately if its translucency degrades over time.

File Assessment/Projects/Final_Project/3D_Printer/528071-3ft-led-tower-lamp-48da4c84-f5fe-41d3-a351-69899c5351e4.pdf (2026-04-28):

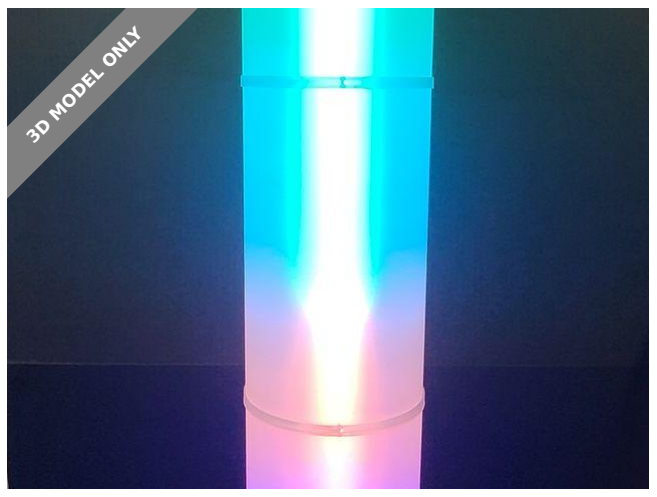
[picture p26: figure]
3D MODEL ONLY

Summary

3Ft Tall Led Tower using WLED.

Hobby & Makers (https://printables.com/model?categoryId=48) > Electronics (https://printables.com/model?categoryId=52)

Tags: led | ledlighting | ledlight

I've made many led lights, most all the designs from here. This is one that's similar to others, but BIGGER :D Go big or go home right?

This was printed on a Kobra Max (410x410x450) , but the largest piece (the base) is 235mm so it can be printed on smaller machines. The diffusors on this are 350mm tall each. This can be easily resized for height, you will just need more connectors.

Printing instructions.

Diffusors are PetG...printed in VASE MODE, with a BRIM, using a 1mm nozzle and whatever speed gives you your desired opacity. I did 35mm and got very clear, so i increased to 45mm and got what you see. The diffusor model is 2mm wide. and the slot for the diffusors (base, connector and lid) are 2mm wide to accomodate elephant foot (from brim) and expansion. Do not use a smaller nozzle in vase, or the diffusor will be too thin and will move around. If your machine is smaller Z axis, resize in Z only.

Badkitty (https://printables.com/@Badkitty)

## 3FT LED Tower

Lamp

VIEW IN BROWSER (https://printables.com/model/528071-3ft-led-tower-lamp)

updated 16. 7. 2023 | published 16. 7. 2023

Diffusor connectors are PetG. I used the 1mm nozzle so it was already on, but i think a smaller nozzle would do better. 3 thinner walls may be stronger.

The rest of the pieces, Base, Base Cover, Lid, Column mount are in PLA. Use your own settings for these for speed and quality.

(1) 1.5'' PVC tube is required for the inner structure the led mount too. Sized to the height you will print (if you change it). 8 strips of led will surround the circumference of this tube. Plan the amount of LEDs you need accordingly.
(1) Power supply will differ if you go bigger or shorter, but i used this one https://amzn.to/43uxf22 408led at 100% white pulls 25a. This PS is 30a, so that covers the 80% max duty recommended. The base cover has tabs to hold this particular PS in place along with using some gorilla glue double-sided tape (though other PS of less power are about the same size anyway)
(1) D1 Mini is required https://amzn.to/3pTGJpS . Other boards can be used, but you will have to custom fit it (base cover as slot specifically for D1)

WS2812B leds are required. https://amzn.to/3DcmR4y , buy enough for whatever height you end up printing.

Any old extension cord you have can be cut and tied into the power supply.

Assembly is quite straight forward. Print, test fit and set aside until all pieces are done.

Start with installing WLED into the D1 Mini.
https://install.wled.me/

Here is a good video if you've never done this.

After you install Wled to the D1 proceed with the next steps.

Install power supply to the base cover, i used double-sided tape). Solder 3 wires (red\grn\blk) to D1 mini in the 5V (red), GND (blk) , D4 pin (Green data). Seat the D1 into the slot (i used hot glue to keep in place) The 5v and Gnd wires connect to 1 set of V+\V- on the power supply, Leave the data wire for later.

Test fit all you diffusors and connectors together. Place in the base. Fit the PVC tube in the base and use a straight rule to mark the height to cut on the PVC tube. The LID has 15mm of travel where the diffusors sit, this gives some good grip on the pvc and diffusors so they don't move. Cut the PVC to fit.

Now cut your LEDs so they're 4inches shorter than your PVC tube. This gives 2 inches to both ends for wiring. Lay out your strips and attach them to the PVC with about 4mm in between. PAY ATTENTION to the direction of the DATA of each strip (the little black arrows) One strip goes up, the next goes down..etc.

Now that all your strips are laid out. Drill 8 hole at the BOTTOM of the tube under each strip, to allow the wires through into the base. Choose a strip to be the FIRST in the series, this have the DATA wire soldered to it from the D1 mini's D4 pin, along with 5v\Gnd wires from power supply. (see photos). The remaining strips only get 5v\Gnd wire soldered and run into the hole. Once you have all 7 5v\gnd wires soldered and run into their holes (and the 5v\data\gnd for the first strip) it's time to run the DATA.

Find your FIRST strip (with 5v\gnd\data) and go to the top of this strip. You will solder a DATA wire on the DATA pin from this strip to the next strip (next strip should have an arrow pointing DOWN). Next follow the arrows and solder a DATA wire to each strip according to their direction. The last strip goes nowhere, it's the end of the line.

Once all your wires are soldered, insert the COLUMN MOUNT into the BASE. I glued these together for added support (even though it was a snug fit). Insert the PVC tube bottom into the tube, routing the wires through.

Now it's time to bundle up the LED strip wires. Tie all the 5v together then all the gnd together (see photo) Add one length of wire to each, to connect to the power supply, the other open set of V+\V- The DATA wire from the strips connects to the DATA wire coming from the D1 mini. Use the 120v extension cable you have, cut the female end off of it, strip the wires and connect them to the Load and Neutral on the power supply. There are 3 posts on the base cover, these are there to wrap the power cord around to prevent pulling the cord out of the base. (see photo)

With everything secured and tied up, test your setup and make sure all led strips light up. Default setup for WLED is only like 30leds or so. Go into WLED and set to the amount you have.

Once all LED are on and tested, route the wires so they fit inside the base and you can close the cover to the base. Use 4 small screws to secure the cover.

Now, install each diffusor your printed with a connector. Then put the lid on the top and you're all set to go.

I suggest, learn how to setup “segments” in WLED so you can tell WLED that each strip is it's own and then use “reverse direction” on the odd numbers strips, so they all work from the bottom up (instead of in series which would be bottom to top , then top to bottom on the next strip)

## Model files

License

This work is licensed under a
Creative Commons (4.0 International License)

Attribution—Noncommercial—Share Alike (http://creativecommons.org/licenses/by-nc-sa/4.0/)

✖ | Sharing without ATTRIBUTION
✔ | Remix Culture allowed
✖ | Commercial Use

diffuser.stl

column⁻mount.stl

lid-3.stl

base.stl

base⁻cover.stl

diffusor⁻connector.stl

✖ | Free Cultural Works
✖ | Meets Open Definition

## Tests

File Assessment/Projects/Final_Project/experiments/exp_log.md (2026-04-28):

# Experiment Log

> Append-only. Each entry: date / configuration change / val acc / test acc / on-device / observation / figure paths.

---

## Entry template

```
### YYYY-MM-DD — <short title>

- **Configuration change**: <what differs from baseline>
- **Validation accuracy**: <%>
- **Test accuracy (INT8)**: <% @ threshold>
- **On-device**: inference <ms> / RAM <KB> / flash <KB> / DSP <ms>
- **Observation**: <one or two sentences>
- **Figures**: `report_figures/03_experiments/<exp_dir>/...`
```

---

## 2026-04-27 — Design decision: MFCC FFT length (autotune → manual)

- **Context**: EI Autotune suggested `FFT length = 512` for the MFCC block.
- **Issue**: with FFT 512 the DSP processing time on Cortex-M4F was estimated at **416 ms**, well above the 100 ms real-time budget for a keyword spotting loop.
- **Action**: manually reduced `FFT length` to `256`, keeping all other MFCC parameters (13 coef, frame 0.025 / stride 0.02 s, 32 filters, low_freq 80 Hz) unchanged.
- **Result**: DSP time dropped to **296 ms** (−29%). Feature explorer separability inspected visually after change — no obvious degradation.
- **Trade-off acknowledged**: 296 ms still exceeds the 100 ms target, but inference itself is only 4 ms; the dominant cost is MFCC computation, not the model. Further DSP cuts (e.g. fewer filters, shorter frame) deferred to a possible later experiment.
- **Figures**:
  - `report_figures/02_methods/mfcc_autotune_default.png` (autotune default, FFT 512, DSP 416 ms)
  - `report_figures/02_methods/mfcc_manual_tuned.png` (manual choice, FFT 256, DSP 296 ms)

---

## 2026-04-27 — Baseline (EI default 1D CNN, MFCC, INT8 + Float32)

- **Configuration**:
  - DSP: 13 MFCC coef, frame 0.025 / stride 0.02 s, FFT 256 (manually chosen, see entry above), 32 filters, low_freq 80 Hz
  - Model: EI default 1D CNN — Input 637 → Reshape (13 cols) → Conv1D 8 filters / kernel 3 → Dropout 0.25 → Conv1D 16 filters / kernel 3 → Dropout 0.25 → Flatten → Dense 6
  - Training: 200 epochs, lr 0.005, batch 32, val 20%, CPU; learned optimizer disabled; full augmentation (add noise / mask time / mask freq all Low, warp time on); profile int8 enabled
- **Validation accuracy**: 94.5% (INT8) / 95.1% (Float32) — loss 0.19 both
- **Test accuracy**: 81.95% (INT8) / 82.44% (Float32) — assumed threshold 0.6 (UNCERTAIN column visible)
- **On-device (INT8, autoreported by EI)**: inference ~4 ms / RAM ~12.5 KB / flash ~46.4 KB / DSP 296 ms
- **Per-class observation (INT8 test set)**:
  - `noise` 80% (→ unknown 14.3%, harmless)
  - `reading` 100%
  - `sleep` 90%
  - `turn_off` 76.7% (→ uncertain 13.3%, → turn_on 6.7%)
  - **`turn_on` 56.7%** (→ uncertain 26.7%, → turn_off 10%) — single worst class
  - `unknown` 86%
  - F1 ranks: reading 0.94 > sleep 0.92 > noise 0.89 > unknown 0.84 > turn_off 0.82 > **turn_on 0.69**
- **Quantization cost (free comparison)**: INT8 vs Float32 — val −0.6 pp, test −0.49 pp; turn_on confusion to turn_off jumps from 7.4% (Float32 val) to 11.1% (INT8 val) — quantization cost concentrated on the most confusable pair, not uniform.
- **Generalisation gap**: val 94.5% → test 81.95% = **−12.55 pp** (consistent with §7 limitation #4); much larger than the 0.49 pp quantization cost — generalisation, not quantization, is the bottleneck.
- **Figures**:
  - `report_figures/03_experiments/baseline/baseline_architecture.png`
  - `report_figures/03_experiments/baseline/baseline_hyperparams.png`
  - `report_figures/03_experiments/baseline/baseline_val_int8.png`
  - `report_figures/03_experiments/baseline/baseline_val_float32.png`
  - `report_figures/03_experiments/baseline/model_test_int8.png`
  - `report_figures/03_experiments/baseline/model_test_float32.png`

---

## 2026-04-28 — exp_wider (Conv 8/16 → 16/32)

- **Configuration change vs baseline**: Conv1D layer 1 filters 8 → **16**, Conv1D layer 2 filters 16 → **32**. All other MFCC / training / augmentation / training-hyperparam settings unchanged.
- **Hypothesis**: turn_on / turn_off confusion (turn_on F1 0.69 in baseline) may be capacity-bound — wider conv channels could capture finer fricative-tail differences.
- **Validation accuracy**: **96.3% (INT8, loss 0.49) / 95.7% (Float32, loss 0.21)** — note INT8 *higher* than Float32 on accuracy but with higher loss → quantization preserves argmax but lowers confidence on correctly classified samples.
- **Test accuracy**: **82.93% (INT8) / 82.93% (Float32)** @ threshold 0.6 — confusion matrices identical (argmax stable under quantization); only AUC differs (0.96 vs 0.98).
- **On-device (INT8 estimate, EI auto-reported)**: inference **7 ms** (vs baseline 4 ms, +75%) / Peak RAM **14.0 KB** (+12%) / Flash **49.4 KB** (+6%) / DSP 296 ms (unchanged). All well within MCU budgets (Cortex-M4F: 256 KB RAM, 1 MB Flash; real-time budget 100 ms). **Hardware capacity is not the bottleneck** — wider model fits comfortably; the problem with wider is purely behavioural (calibration / failure mode).
- **Per-class observation (INT8 test set, vs baseline)**:
  - `turn_on` 56.7% → **63.3%** ✅; F1 0.69 → **0.76** ✅
  - **but** `turn_on → turn_off` 10.0% → **33.3%** ❌ (×3.3) ; `turn_on → uncertain` 26.7% → 3.3%
  - `turn_off` 76.7% → 90% ✅; `turn_off → turn_on` 6.7% → 0% ✅
  - `noise` 80% → 65.7% (→ unknown 25.7%, harmless distractor confusion)
  - `sleep` 90% → 86.7%; `unknown` 86% → 90%; `reading` 100% → 100%
  - F1 ranks (worst → best): turn_on 0.76, turn_off 0.81, noise 0.79, unknown 0.83, sleep 0.91, reading 0.98
- **Quantization robustness gain (free finding)**: test-set quantization cost 0 pp (vs −0.49 pp in baseline). Wider channels provide redundancy that absorbs per-weight quantization noise; argmax stays stable under INT8.
- **Generalisation gap**: val 96.3% → test 82.93% = **−13.37 pp** (vs baseline −12.55 pp). Wider model *overfits harder*; it is not a generalisation fix.
- **Verdict (vs baseline)**: **deployment-worse despite higher headline accuracy**. The +1 pp aggregate accuracy and improved turn_on F1 hide a **3× rise in confidently-wrong turn_on→turn_off triggers** (10% → 33.3%). The wider model trades polite "uncertain → no response" failures for harmful "confident wrong action" failures. For a safety-relevant state machine, baseline is preferred. Diagnosis: turn_on/turn_off confusion is **not capacity-bound** — adding capacity worsens calibration without resolving the underlying acoustic similarity (consistent with §7 limitation #1: shared first ~800 ms of pronunciation). Likely a data problem: single-speaker, limited count.
- **Figures**:
  - `report_figures/03_experiments/exp_wider/wider_architecture.png` (Conv 16/32)
  - `report_figures/03_experiments/exp_wider/wider_hyperparams.png` (identical to baseline)
  - `report_figures/03_experiments/exp_wider/wider_val_int8.png`
  - `report_figures/03_experiments/exp_wider/wider_val_float32.png`
  - `report_figures/03_experiments/exp_wider/wider_test_int8.png`
  - `report_figures/03_experiments/exp_wider/wider_test_float32.png`

---

## 2026-04-28 — exp_dense (no Conv — sanity check)

- **Configuration change vs baseline**: removed both Conv1D + Dropout layers; replaced with Flatten → Dense 32 (ReLU) → Dense 6. All other MFCC / training / augmentation / training-hyperparam settings unchanged.
- **Hypothesis**: MFCC already extracts strong spectro-temporal features; a small dense head may approach CNN performance — testing whether convolution is actually pulling weight here.
- **Validation accuracy**: **75.0% (INT8, loss 0.86) / 75.0% (Float32, loss 0.69)** — same accuracy, INT8 loss noticeably higher (confidence margin shrunk by quantization).
- **Test accuracy**: **61.95% (INT8) / 62.44% (Float32)** @ threshold 0.6 — quantization cost only −0.49 pp (INT8 vs Float32 confusion matrices nearly identical; AUC 0.93 both).
- **On-device (INT8 estimate, EI auto-reported)**: inference **1 ms** (vs baseline 4 ms, −75%) / Peak RAM **1.8 KB** (vs 12.5 KB, −86%) / Flash **34.1 KB** (vs 46.4 KB, −26%) / DSP 296 ms (unchanged). Smallest of all three models — but cheapest does not mean best.
- **Per-class observation (INT8 test set, vs baseline)**:
  - `noise` 80% → **40%** ❌ (→ uncertain 45.7%; dense model essentially blind to background noise)
  - `reading` 100% → 93.3% (still strong; phonetically distinctive)
  - `sleep` 90% → **56.7%** ❌ (→ uncertain 26.7%, → unknown 10%)
  - `turn_off` 76.7% → 83.3% ✅ (slightly better, but see turn_on below)
  - **`turn_on` 56.7% → 43.3%** ❌ (→ turn_off **23.3%** — 2.3× worse than baseline 10%; → uncertain 30%); F1 0.69 → **0.55**
  - `unknown` 86% → 60% ❌
  - F1 ranks (worst → best): noise 0.51, turn_on 0.55, sleep 0.68, unknown 0.69, turn_off 0.76, reading 0.90
- **Strange "val turn_on" inversion**: on the val set turn_on is the model's *best* class (90.5% recall). On test it collapses to 43.3% (worst). This is the largest val→test per-class swing in any experiment so far — strong evidence that turn_on/turn_off separation in dense is memorisation, not learned representation. Conv 1D's local receptive field appears to capture the "on/off" tail-frame pattern in a way that survives distribution shift; flat dense does not.
- **Generalisation gap**: val 75.0% → test 61.95% = **−13.05 pp** (vs baseline −12.55 pp, wider −13.37 pp). Gap roughly the same in absolute pp, but the *floor* dropped 20 pp — same drift, much worse starting point.
- **Verdict (vs baseline)**: **CNN justification confirmed (yes)**. Dense model loses 20 pp test accuracy and breaks two safety-relevant classes (noise blindness, turn_on collapse) for a 4× RAM saving the MCU does not need. Conv layers do real work — they are not just decorative capacity, they extract the local time-frequency features that MFCC alone leaves implicit. This is a useful negative result: it falsifies the "MFCC already does the heavy lifting" hypothesis and locks Conv1D in as a load-bearing choice for the rest of the design.
- **Figures**:
  - `report_figures/03_experiments/exp_dense/dense_architecture.png` (Reshape → Flatten → Dense 32 → Output 6)
  - `report_figures/03_experiments/exp_dense/dense_hyperparams.png` (identical to baseline)
  - `report_figures/03_experiments/exp_dense/dense_val_int8.png`
  - `report_figures/03_experiments/exp_dense/dense_val_float32.png`
  - `report_figures/03_experiments/exp_dense/dense_test_int8.png`
  - `report_figures/03_experiments/exp_dense/dense_test_float32.png`
  - `report_figures/03_experiments/exp_dense/dense_ondevice.png`

---

## 2026-04-28 — Live testing on deployed Nano 33 BLE Sense (baseline INT8 firmware)

- **Firmware**: `arduino/echolume/echolume.ino` running the baseline INT8 model from EI export `ei-xms.12138-project-1-arduino-1.0.1-impulse-#1.zip`. `CONFIDENCE_THRESHOLD = 0.60` (matches EI test-set evaluation threshold). `STATE_LOCK_DURATION = 1000 ms`. WS2812B strip on D2, 10 LEDs, brightness capped at 150/255.
- **Protocol**:
  - 4 action keywords tested live: `turn_on`, `turn_off`, `reading`, `sleep`. `noise` and `unknown` are not action classes and were not actively prompted; bystander speech encountered during the session is captured under "false triggers" below.
  - **100 trials total**: author 80 (20 per keyword) + helper 20 (5 per keyword). Helper: male, 23 y, native Mandarin, no prior exposure to the system.
  - Mouth-to-mic distance varied **0.05 m – 0.5 m** (close to mid-range desk use).
  - Environment: quiet indoor room. Approximately half of the trials were run with **light background music** playing softly to probe robustness; the other half in silence.
  - **Outcome metric**: a trial is "correct" if and only if the WS2812B strip transitions to the intended state (i.e. the FSM-level outcome, not the raw classifier output). This is more forgiving than per-frame argmax because the 1 s state lock and FSM legality checks discard chatter, but it is the metric that matters for the deployed application.
- **Aggregate result**: **88 / 100 = 88.0 %** correct state transitions.
  - Author: 71 / 80 = 88.75 %
  - Helper: 17 / 20 = 85.0 %
- **Per-keyword breakdown** (⚠️ **reconstructed approximation** — per-trial outcomes were not logged; the totals above and the qualitative ranking below are exact, but the integer split across keywords is reconstructed from the user's spoken observations and is consistent with the baseline EI test-set failure pattern):
  - `reading`  24 / 25 (96 %)  — "particularly good"
  - `sleep`    24 / 25 (96 %)  — "particularly good"
  - `turn_off` 22 / 25 (88 %)
  - `turn_on`  18 / 25 (72 %)  — single worst keyword, consistent with baseline F1 ranking (turn_on 0.69)
- **Failure modes**:
  1. **Missed wake on `turn_on`** (dominant). The author reports never observing a `turn_on` utterance trigger a wrong-state transition; the failure was always "no response" — the highest-confidence class fell below 0.60 and the FSM stayed in OFF. This matches the baseline EI test set behaviour where `turn_on` confusion is concentrated in the `uncertain` column (26.7 %), not in the `turn_off` column.
  2. **False triggers from bystander speech** (1–2 events, **not counted in the 12 failures above**). During the helper's session, a third party walked past speaking nearby and the lamp transitioned to a non-intended state. The author's own session produced no false triggers. These events are real-world failures but were not logged at the time; recording would have moved aggregate accuracy from 88 / 100 down toward 86–87 / 100.
- **Comparison to EI test set (INT8 @ 0.6)**:

  | Keyword | EI test set | Live test (reconstructed) |
  |---|---|---|
  | reading | 100.0 % | 96 % |
  | sleep | 90.0 % | 96 % |
  | turn_off | 76.7 % | 88 % |
  | turn_on | 56.7 % | 72 % |
  | **aggregate (action classes)** | 81.95 % (all 6 classes) | **88.0 %** (4 action classes) |

  Live aggregate is higher than EI test set aggregate. Two plausible reasons: (a) the primary speaker on live test is also the primary speaker in the training set, reducing speaker-mismatch error; (b) the FSM-level "correct switch" criterion is more lenient than per-frame argmax — the 1 s state lock and legal-transition guard collapse many `uncertain` predictions into a benign "no action" rather than a wrong action.
- **Verdict**: deployment is functional at 88 % aggregate live accuracy with the dominant failure mode being polite no-response on `turn_on` (recoverable by the user simply repeating the command) rather than confidently-wrong state changes — the safer of the two failure shapes for a state-machine application. The bystander false-trigger mode is a known weakness inherited from the dataset (no "rejection" class beyond `noise` / `unknown`) and is the most plausible target for future work (e.g. wake-word gating, voice activity threshold tuning).
- **Figures**:
  - `report_figures/04_testing/live_test_per_keyword.png`
  - `report_figures/04_testing/live_test_vs_ei.png`
  - `report_figures/05_hardware/` (4 photographs of the assembled hardware — captions TBD)

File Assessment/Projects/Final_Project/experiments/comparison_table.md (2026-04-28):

# Comparison Table

> Append new experiments as new columns. **Do not remove the baseline column.**
> All rows reflect the model under INT8 quantization unless noted. `_` = pending.

| Metric | baseline | exp_wider | exp_dense |
|---|---|---|---|
| Architecture | Conv 8 → Conv 16 → Flatten → Dense 6 | Conv **16** → Conv **32** → Flatten → Dense 6 | (no Conv) Flatten → Dense 32 → Dense 6 |
| Conv kernel | 3 | 3 | — |
| Dropout | 0.25 | 0.25 | — |
| DSP | MFCC (13 coef, frame 0.025/0.02s, FFT 256) | same | same |
| Augmentation | EI Low + warp time | same | same |
| Training | 200 ep / lr 0.005 / batch 32 / val 20% / CPU | same | same |
| **Val acc — Float32** | 95.1% | 95.7% | 75.0% |
| **Val acc — INT8** | 94.5% | **96.3%** | 75.0% |
| **Test acc — Float32** @ 0.6 | 82.44% | 82.93% | 62.44% |
| **Test acc — INT8** @ 0.6 | 81.95% | **82.93%** | **61.95%** ❌ |
| **Quantization Δ (test)** | −0.49 pp | **0 pp** ✅ | −0.49 pp |
| **Val→Test gap (INT8)** | −12.55 pp | **−13.37 pp** ⚠️ | −13.05 pp |
| Worst-class F1 (INT8 test) | turn_on 0.69 | turn_on 0.76 | **noise 0.51** / turn_on 0.55 |
| turn_on accuracy (INT8 test) | 56.7% | 63.3% | **43.3%** ❌ |
| **turn_on → turn_off (INT8 test)** | 10.0% | **33.3%** ❌ | 23.3% ❌ |
| turn_on → uncertain (INT8 test) | 26.7% | 3.3% | 30.0% |
| turn_off accuracy (INT8 test) | 76.7% | 90.0% | 83.3% |
| noise accuracy (INT8 test) | 80.0% | 65.7% | **40.0%** ❌ |
| Inference (ms, INT8 est.) | ~4 | **7** (+75%) | **1** (−75%) |
| Peak RAM (KB, INT8 est.) | ~12.5 | **14.0** (+12%) | **1.8** (−86%) |
| Flash (KB, INT8 est.) | ~46.4 | **49.4** (+6%) | **34.1** (−26%) |
| DSP (ms, fixed) | 296 | 296 | 296 |
| **Verdict** | reference; safest failure mode | +1 pp aggregate, but turn_on→turn_off **×3.3** worse — deployment-worse despite higher F1 | −20 pp test acc; noise blindness + turn_on collapse — confirms Conv layers are load-bearing |

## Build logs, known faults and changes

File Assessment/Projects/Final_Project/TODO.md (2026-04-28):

# EchoLume — Project TODO

按模块列出未完成项与所需图表/文件。打勾即完成。

---

## 1. Firmware（`arduino/echolume/echolume.ino`）

- [ ] **[阻塞]** 接入 WS2812B：`Adafruit_NeoPixel` 库 + 引脚定义（D2 或 D3 待定）
- [ ] 状态 → 颜色映射：
  - `STATE_OFF` → 全灭
  - `STATE_GENERAL` → 白光
  - `STATE_READING` → 暖黄
  - `STATE_SLEEP` → 暗红呼吸（需要在 loop 里做非阻塞 fade）
- [ ] 上电自检：开机闪两下确认硬件正常
- [ ] **检查 `CONFIDENCE_THRESHOLD`**：当前代码 `0.75`，但 baseline 评估表用 `0.6` / `0.5`。统一阈值或在实验日志里说明阈值漂移
- [ ] Serial 调试：除状态切换外，加 `best_label / best_value` 周期性输出（DEBUG 宏控制开关）
- [ ] 在 `experiments/exp_log.md` 里记录上板验证结果（推理耗时、内存、串口截图）

---

## 2. Edge Impulse / 模型

- [ ] 把 `edge_impulse/dsp_config.json` 从 EI Studio 导出参数填实（目前是空 `{}`）
- [ ] 补 `edge_impulse/model_metadata.md`：项目链接、Project ID、最近一次 train/sync 时间
- [ ] 决定是否做对比实验，候选维度（**未承诺数量**，每多一组都要有动机）：
  - DSP：MFCC vs MFE / 不同 coef 数 / 不同 frame stride
  - 架构：1D CNN vs 2D CNN / Conv 通道数加倍
  - 量化：float32 vs INT8 直接对比（已有 INT8，缺 float32 baseline）
  - 数据增强：完整增强 vs 关闭增强
- [ ] 任何新实验：在 `experiments/exp_log.md` 追加，在 `experiments/comparison_table.md` 加一列

---

## 3. 数据相关图表（`report_figures/01_data/`）

- [ ] `class_distribution.png` — 6 类样本数柱状图（已有数字，画即可）
- [ ] `sample_duration_hist.png` — 每类样本时长分布
- [ ] `waveform_examples.png` — 每类挑 1 条样本的波形图（4×1 或 2×3 拼图）
- [ ] `mfcc_turn_on_vs_off.png` — `turn_on` 与 `turn_off` 的 MFCC 时间轴对比（直接支撑 §7 局限性 1）
- [ ] `recording_setup.jpg` — 录音环境照片（设备、距离、房间），说明数据采集条件

---

## 4. 方法/系统图表（`report_figures/02_methods/`）

- [ ] `system_overview.png` — Mic → MFCC → CNN → State Machine → WS2812B 框图
- [ ] `model_architecture.png` — 模型结构图（Conv8 → Conv16 → Flatten → Dense6 + 输入维度标注）
- [ ] `state_machine.png` — §6 状态转移图（drawio / mermaid 导出）

---

## 5. Baseline 实验图表（`report_figures/03_experiments/baseline/`）

- [ ] `training_curves.png` — Loss & accuracy（train vs val）双子图
- [ ] `confusion_matrix_val.png` — 验证集混淆矩阵
- [ ] `confusion_matrix_test_int8.png` — 测试集 INT8 混淆矩阵（threshold 0.6）
- [ ] `per_class_f1.png` — 每类 precision / recall / F1 柱状图
- [ ] `threshold_sweep.png` — 阈值 0.3–0.9 vs accuracy / FPR / FNR 曲线（直接支撑 §7 局限性 5）
- [ ] `ei_studio_metrics.png` — EI Studio 截图（on-device 性能 4ms/12.5KB/46.4KB/258ms）

> 后续实验：每加一组，在 `report_figures/03_experiments/exp_<name>/` 下复刻同一套图，便于横向比较。

---

## 6. 真机测试图表（`report_figures/04_testing/`）

- [ ] 设计测试协议：每个关键词 × N 次 × M 种环境（安静 / 背景音乐 / 多人）
- [ ] `live_test_confusion.png` — 真机测试结果混淆矩阵
- [ ] `failure_cases.md` + 对应音频片段（如能录到）—— 反思章节素材
- [ ] 真机测试视频片段（也用于 3 分钟视频）

---

## 7. 硬件图表（`report_figures/05_hardware/` + `docs/hardware_setup.md`）

- [ ] BOM 表（型号、数量、来源）— 填到 `docs/hardware_setup.md`
- [ ] `wiring_diagram.png` — Fritzing 或手绘接线图（Nano + WS2812B + 电源）
- [ ] `device_photo.jpg` — 实物正面 + 侧面照
- [ ] `enclosure_render.png` — 3D 外壳渲染图
- [ ] `enclosure.stl` — 放在 `docs/` 或 `hardware/`（视后续是否新建目录）
- [ ] 3D 打印：参数（材料、层高、填充率）记录到 `hardware_setup.md`

---

## 8. 报告（`../../Report/report.md`，1500 字 ±20%）

> 报告按课程要求放在 `Assessment/Report/`，与 `Assessment/Projects/` 同级。`Report/` 下当前文件：`README.md`（课程模板原貌，**不动**）、`report.md`（正在写的版本）、`outline.md`、`references.bib`、`ProjectIdea.md`。

按 9 个章节推进，建议顺序：

- [ ] **Methods（先写，骨架最稳）** — Application Overview + Data + Model
- [ ] **Experiments** — baseline 已有结果先成稿，对比实验后补
- [ ] **Results and Observations** — 含 critical reflection 的 5 条（已在 CLAUDE.md §7）
- [ ] **Introduction** — 末写，避免反复改
- [ ] **Research Question** — 1–2 句
- [ ] **Bibliography** — 同步填 `../../Report/references.bib`（核心引用：Warden 2018 / Reddy 2019 / Zhang 2017）
- [ ] **Declaration of Authorship** — 签名 + 日期
- [ ] 字数核查 + 导出 PDF（VSCode Markdown PDF 扩展）

---

## 9. 视频（3 分钟，30%）

- [ ] 故事板：开场（问题 / 用户场景，~30s）→ 技术（~90s）→ 演示（~45s）→ 反思（~15s）
- [ ] 拍摄：真机操作镜头、串口输出、训练曲线、混淆矩阵
- [ ] 配音 / 字幕脚本
- [ ] 剪辑 + 上传

---

## 10. 提交前检查清单

- [ ] `report.md` 字数在 1200–1800 之间
- [ ] 所有图都有 caption + figure number，正文有引用
- [ ] `references.bib` 全部引用都在正文出现
- [ ] `git status` 干净（CLAUDE.md / .claude / .claudeignore 仍被 .gitignore 屏蔽）
- [ ] GitHub 仓库 README 指向 report PDF
- [ ] Moodle 上传 PDF + 视频
- [ ] Edge Impulse 项目设为 public 或在 metadata 里给出可访问链接

---

## 阻塞依赖图（粗）

```
WS2812B 接线 ──► firmware 灯光控制 ──► 真机测试 ──► 视频拍摄
                                          │
                                          └► 04_testing 图表
对比实验决策 ──► 实验执行 ──► 03_experiments/exp_*/ 图表 ──► 报告 Experiments 章
                                                              │
                                                              └► Results & Reflection
```

最关键路径：**WS2812B 接线 → firmware 灯光 → 真机测试**。这条不通，视频和 testing 章节都没法做。

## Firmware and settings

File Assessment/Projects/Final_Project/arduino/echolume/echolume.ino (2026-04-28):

#define EIDSP_QUANTIZE_FILTERBANK   0

/* Includes ---------------------------------------------------------------- */
#include <PDM.h>
#include <xms.12138-project-1_inferencing.h>
#include <Adafruit_NeoPixel.h>  // WS2812 LED strip control

// --- WS2812 LED strip configuration ---
#define LED_PIN    2      // WS2812 data line on D2
#define NUM_LEDS   10     // Number of LEDs

// NeoPixel object
Adafruit_NeoPixel strip(NUM_LEDS, LED_PIN, NEO_GRB + NEO_KHZ800);

/** Audio buffers, pointers and selectors */
typedef struct {
    int16_t *buffer;
    uint8_t buf_ready;
    uint32_t buf_count;
    uint32_t n_samples;
} inference_t;

static inference_t inference;
static signed short sampleBuffer[2048];
static bool debug_nn = false;

enum LampState {
    STATE_OFF,
    STATE_GENERAL,
    STATE_READING,
    STATE_SLEEP
};

LampState current_state = STATE_OFF;
LampState previous_state = STATE_OFF;

unsigned long last_state_change_ms = 0;
const unsigned long STATE_LOCK_DURATION = 1000;

// Confidence threshold (matches EI Model testing setting at 0.6)
const float CONFIDENCE_THRESHOLD = 0.60f;
// ==========================================

// Helper: set all LEDs to a single colour
void setAllLeds(uint8_t r, uint8_t g, uint8_t b) {
    for(int i=0; i<NUM_LEDS; i++) {
        strip.setPixelColor(i, strip.Color(r, g, b));
    }
    strip.show();
}

void setup() {
    Serial.begin(115200);
    while (!Serial);
    Serial.println("Smart Lamp with 1s State Lock Started.");

    // Initialise LED strip
    strip.begin();
    // Cap overall brightness (0-255) to limit current draw on 3.3V rail
    strip.setBrightness(150);
    strip.show(); // Start with all LEDs off

    run_classifier_init();

    if (microphone_inference_start(EI_CLASSIFIER_SLICE_SIZE) == false) {
        ei_printf("ERR: Could not allocate audio buffer\r\n");
        return;
    }

    ei_printf("\n--- System Ready (Lock active) ---\n");
    ei_printf("Current State: [ OFF ]\n");
}

void loop() {
    bool m = microphone_inference_record();
    if (!m) return;

    signal_t signal;
    signal.total_length = EI_CLASSIFIER_SLICE_SIZE;
    signal.get_data = &microphone_audio_signal_get_data;
    ei_impulse_result_t result = { 0 };

    EI_IMPULSE_ERROR r = run_classifier_continuous(&signal, &result, debug_nn);
    if (r != EI_IMPULSE_OK) return;

    float best_value = 0.0;
    const char* best_label = "";
    for (size_t ix = 0; ix < EI_CLASSIFIER_LABEL_COUNT; ix++) {
        if (result.classification[ix].value > best_value) {
            best_value = result.classification[ix].value;
            best_label = result.classification[ix].label;
        }
    }

    unsigned long now = millis();

    if (best_value >= CONFIDENCE_THRESHOLD) {

        if (now - last_state_change_ms >= STATE_LOCK_DURATION) {

            LampState next_state = current_state;

            if (strcmp(best_label, "turn_on") == 0) {
                if (current_state == STATE_OFF) next_state = STATE_GENERAL;
            }
            else if (strcmp(best_label, "turn_off") == 0) {
                if (current_state != STATE_OFF) next_state = STATE_OFF;
            }
            else if (strcmp(best_label, "reading") == 0) {
                if (current_state != STATE_OFF) next_state = STATE_READING;
            }
            else if (strcmp(best_label, "sleep") == 0) {
                if (current_state != STATE_OFF) next_state = STATE_SLEEP;
            }

            if (next_state != current_state) {
                current_state = next_state;
                last_state_change_ms = now;
            }
        }
    }

    // Update LED colour on state change
    if (current_state != previous_state) {
        switch (current_state) {
            case STATE_OFF:
                ei_printf("Current State: [ OFF ]\n");
                setAllLeds(0, 0, 0); // Lights off
                break;
            case STATE_GENERAL:
                ei_printf("Current State: [ GENERAL MODE ]\n");
                setAllLeds(0, 255, 200); // Ice blue
                break;
            case STATE_READING:
                ei_printf("Current State: [ READING MODE ]\n");
                setAllLeds(255, 255, 255); // Pure white
                break;
            case STATE_SLEEP:
                ei_printf("Current State: [ SLEEP MODE ]\n");
                setAllLeds(255, 50, 0); // Warm orange-red
                break;
        }
        previous_state = current_state;
    }
}

// ---- PDM microphone callbacks (EI library boilerplate) ----
static void pdm_data_ready_inference_callback(void) {
    int bytesAvailable = PDM.available();
    int bytesRead = PDM.read((char *)&sampleBuffer[0], bytesAvailable);
    if (inference.buf_ready == 0) {
        for(int i = 0; i < bytesRead>>1; i++) {
            inference.buffer[inference.buf_count++] = sampleBuffer[i];
            if(inference.buf_count >= inference.n_samples) {
                inference.buf_count = 0; inference.buf_ready = 1; break;
            }
        }
    }
}

static bool microphone_inference_start(uint32_t n_samples) {
    inference.buffer = (int16_t *)malloc(n_samples * sizeof(int16_t));
    if(inference.buffer == NULL) return false;
    inference.buf_count = 0; inference.n_samples = n_samples; inference.buf_ready = 0;
    PDM.onReceive(&pdm_data_ready_inference_callback);
    PDM.setBufferSize(4096);
    if (!PDM.begin(1, EI_CLASSIFIER_FREQUENCY)) { microphone_inference_end(); return false; }
    PDM.setGain(127);
    return true;
}

static bool microphone_inference_record(void) {
    inference.buf_ready = 0; inference.buf_count = 0;
    while(inference.buf_ready == 0) { delay(1); }
    return true;
}

static int microphone_audio_signal_get_data(size_t offset, size_t length, float *out_ptr) {
    numpy::int16_to_float(&inference.buffer[offset], out_ptr, length);
    return 0;
}

static void microphone_inference_end(void) {
    PDM.end(); free(inference.buffer);
}

#if !defined(EI_CLASSIFIER_SENSOR) || EI_CLASSIFIER_SENSOR != EI_CLASSIFIER_SENSOR_MICROPHONE
#error "Invalid model for current sensor."
#endif

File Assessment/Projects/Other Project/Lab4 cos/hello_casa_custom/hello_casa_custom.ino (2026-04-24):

/*   
 *   Hello CASA - DL4SN example
 *   Duncan Wilson
 *   November 2020
 *   
 *   Simplified version of the TinyML Hello World code in Ch5 of TinyML book and based on 
 *   example at https://github.com/tensorflow/tensorflow/tree/master/tensorflow/lite/micro/examples/hello_world
 *   
 *   some code and abstraction removed to make it simpler
*/



/*  These applications rely on having the Arduino_TensorFlowLite library installed 
 *  https://www.tensorflow.org/lite/microcontrollers
 *  
 *  Go to "Tools>Manage Libraries" and search for Arduino_TensorFlowLite and hit install if you dont have it installed
*/
#include <TensorFlowLite.h>

// we are including our model in a seperate file to keep the code simpler
#include "model.h"
// we are using a variety of functions from the TensorFlowLite library and need to reference them here
#include "tensorflow/lite/micro/all_ops_resolver.h"
#include "tensorflow/lite/c/common.h"
#include "tensorflow/lite/micro/micro_error_reporter.h"
#include "tensorflow/lite/micro/micro_interpreter.h"
#include "tensorflow/lite/schema/schema_generated.h"
#include "tensorflow/lite/version.h"


/* 
 * In the code below we are defining a number of global variables that we will be using in the sketch 
 */

// Define the variables used by TFLite (pointers)
tflite::ErrorReporter* error_reporter = nullptr;
const tflite::Model* model = nullptr;
tflite::MicroInterpreter* interpreter = nullptr;
TfLiteTensor* input = nullptr;
TfLiteTensor* output = nullptr;


// Create an area of memory to use for input, output, and intermediate arrays. 
const int kTensorArenaSize = (8 * 1024);
uint8_t tensor_arena[kTensorArenaSize];

// This constant represents the range of x values our model was trained on,
// which is from 0 to (2 * Pi). We approximate Pi to avoid requiring additional libraries.
const float kXrange = 2.f * 3.14159265359f;

// This constant determines number of inferences to perform across range of x values defined above. 
const int kInferencesPerCycle = 8000;

// A counter to keep track of how many inferences we have performed.
int inference_count = 0;


// The pin of the Arduino's built-in LED
int led = LED_BUILTIN;





/*
 * Initialise the sketch - all this code is run once at start-up
 */

void setup() {

  // Set up a tflite mirco error reporter to allow us to log / display data to the terminal. 
  static tflite::MicroErrorReporter micro_error_reporter;
  error_reporter = &micro_error_reporter;


  // Load in the model we have defined in the model.cpp file and map it into a usable data structure. 
  model = tflite::GetModel(g_model);


  // Check to see if the model is valid using the version function in the library and 
  // if not valid then break out of setup since the code probably will not work!
  if (model->version() != TFLITE_SCHEMA_VERSION) {
    TF_LITE_REPORT_ERROR(error_reporter,
                         "Model provided is schema version %d not equal "
                         "to supported version %d.",
                         model->version(), TFLITE_SCHEMA_VERSION);
    return;
  }

  
  // This pulls in all the operation implementations we need (e.g. ReLU, SoftMax)
  // (for more detail on what is available see all_ops_resolver.cc in TensorFlow library)
  // https://github.com/tensorflow/tensorflow/blob/master/tensorflow/lite/micro/all_ops_resolver.cc
  static tflite::AllOpsResolver resolver;


  // Build an interpreter to run the model with and 
  // create a variable that points to the address of that interpreter.
  static tflite::MicroInterpreter static_interpreter(
      model, resolver, tensor_arena, kTensorArenaSize, error_reporter);
  interpreter = &static_interpreter;


  // Allocate memory from the tensor_arena for the model's tensors.
  TfLiteStatus allocate_status = interpreter->AllocateTensors();
  if (allocate_status != kTfLiteOk) {
    TF_LITE_REPORT_ERROR(error_reporter, "AllocateTensors() failed");
    return;
  }


  // Obtain pointers to the model's input and output tensors. 
  // We have one tensor so our input and output reference item 0.
  input = interpreter->input(0);
  output = interpreter->output(0);


  // initialise inference counter to 0.
  inference_count = 0;


  // Set the LED pin to output
  pinMode(led, OUTPUT);  

}


/*
 * The main loop - this will run forever.
 */

void loop() {


  /*
   * The Loop has five main steps:
   *  - work out an input x value
   *  - convert that input value to be the same as the model type (quantized)
   *  - invoke the interpreter to work out an output given an input
   *  - convert the output back into a number between -1 and 1
   *  - map the output into a value between 0 and 255 to change LED brightness
   */

  
/*   
 *  Step 1: work out an input x value 
 */
  // Calculate an x value to feed into the model. 
  // Position is a number between 0 and 1 depending on how far through the
  // inference count cycle we are.
  // We then mulitply that by our range factor to map it between 0 and 2PI.
  // (ie the range of possible x values the model was trained on)
// 1. 获取当前系统运行的毫秒数
  unsigned long current_time = millis(); 

  // 2. 计算当前在 2000 毫秒（2 秒）周期中的位置
  // millis() % 2000 会得到一个从 0 到 1999 循环的数字
  // 除以 2000.0f 将其转换为 0.0 到 1.0 之间的浮点进度
  float position = static_cast<float>(current_time % 2000) / 2000.0f; 

  // 3. 将 0-1 的进度映射到 0 到 2*PI 的 x 轴范围
  float x_val = position * kXrange;
  input->data.f[0] = x_val;

 
/*  
 *  Step 2: invoke the interpreter to work out an output given an input 
 */
  // Run inference, and if an error: report it and break out of loop
  TfLiteStatus invoke_status = interpreter->Invoke();

  // Check to see if invoke went ok                       
  if (invoke_status != kTfLiteOk) {
    TF_LITE_REPORT_ERROR(error_reporter, "Invoke failed on x_val: %f\n",
                         static_cast<double>(x_val));   
    return;
  }


/* 
 *  Step 3: get the output - a number between -1 and 1
 */

  float y_val = output->data.f[0];
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
